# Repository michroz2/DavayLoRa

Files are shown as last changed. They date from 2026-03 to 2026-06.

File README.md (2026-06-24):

# DavayLoRa

Простая «дистанционная кнопка» для вызова на базе ЛоРа с радиусом действия порядка 300 метров.

ПЕРЕДАТЧИК имеет кнопку, а кроме этого: 
- статусный LED (обычно встроенный в кнопку);
- мониторинговый LED, который загорается _практически_ совместно с приёмником;
- дополнительный лед статуса батареи (встроенный лед платы микропроцессора).
- движковый выключатель. 

ПРИЁМНИК имеет:
- исполнительный ЛЕД - собственно вызывающая «лампочка» (состоит из 2 параллельных COB LED-ов);
- Баззер (моторчик с эксцентриком, осуществляющим вибрацию);
- Биппер (пищалка);
- DIP3 - переключатель выбора набора исполнительных элементов. В принципе можно выбрать все, часть или ни одного;
- дополнительный лед статуса, в том числе и батареи (встроенный лед платы микропроцессора).
- движковый выключатель. 

При включении как передатчика, так и приёмника:
- Показывается 1-секундное «приветствие» всеми исполнительными элементами, 
- затем встроенный лед статуса батареи (на передатчике - лед кнопки) выдаёт с интервалом 2 секунды 2 серии с числом вспышек в зависимости от напряжения батареи:
- - voltage > 3.5 - 2 по 1 разу
- - voltage > 3.6 - 2 по 2 раза
- - voltage > 3.7 - 2 по 3 раза
- - voltage > 3.8 - 2 по 4 раза
- - voltage > 4.0 - 2 по 5 раз

Ниже 3.5 вольт каждый прибор поморгает 7 раз и выключается. 
(То же самое, если заряжать от УСБ выключенный прибор.)
Проверка напряжения в дальнейшем происходит каждые 5 минут непрерывной работы.

- Передатчик переходит в режим ожидания _первого_ нажатия на кнопку.
(При этом передатчик не передаёт никаких комманд до первого нажатия.)
- Приёмник переходит в режим ожидания сигналов от передатчика. 
Приёмник никогда не передаёт никаких комманд первый, только отвечает на команды передатчика.
При отсутствии команд от передатчика приёмник с периодичностью 5 секунд выдаёт по 2 коротких вспышки статусным ледом.
- При первом нажатии на кнопку передатчик «просыпается» и начинает посылать команды включения/выключения и «пинги».
- При нажатии на кнопку передатчика передаётся сигнал на приёмник и в случае успешного приёма на приёмнике
срабатывают исполнительные элементы в соответствии с выбором переключателей DIP3. 
- Приёмник посылает ответную комманду, которая в случае успешного приёма передатчиком включает мониторинговый (и статусный) LED передатчика.
Таким образом, испольнительные элементы TX и RX включаются практически одновременно.
- При отпускании кнопки передатчика по команде гасятся исполнительные элементы приёмника и посылается ответная команда
передатчику, по получении которой выключаются мониторинговый и статусный LEDы передатчика.
Таким образом, при успешной связи испольнительные элементы TX и RX включаются и выключаются вместе.
- При отсутствии изменений состояния кнопки, передатчик начинает самостоятельно посылать «пинг» - сигнал с периодичностью 3 секунды.
Этот сигнал, в случае приёма, вызывает однократное мигание статусного ЛЕДа приёмника и ответ приёмника,
который, в свою очередь, в случае успешного приёма передатчиком вызывает однократное мигание статусного ЛЕДа передатчика.
Таким образом, в покое при успешной связи передатчик и приёмник практически синхронно однократно «моргают» с 
периодичностью 3 секунды.
- Включенные исполнительные элементы приёмника продолжительно работают максимально 2 секунды, после чего выключаются
(НЕ посылая сигнала об этом на передатчик). Поэтому при очень длительном нажатии на кнопку исполнительные 
элементы приёмника включаются каждые 3 секунды (по «пингу») и выключаются через 2 секунды после включения.
- При отсутствии ответа от приёмника передатчик с периодичностью 3 секунды выдаёт по 2 коротких вспышки статусным («кнопочным») ледом
(вместо нормально одной).
Таким образом: однократное «моргание» раз в 3 секунды - связь есть, а 2-х кратное моргание приёмника либо передатчика - связи нет.
- Если в течение часа не происходит нажатия кнопки, передатчик перестаёт посылать «пинг» и переходит в режим ожидания первого нажатия на кнопку.
(При этом приёмник, как и в случае потери сигнала, с периодичностью 5 секунд выдаёт по 2 коротких вспышки статусным ледом.)  

Взаимная настройка приёмника и передатчика (рабочей пары) производится в коде синхронным изменением частоты и/или рабочего адреса команд и последующей прошивкой. 

- 10.01.2022  - 	«причёсан» предыдущий код. Добавлены схемы соединения. Новый репозиторий github.
- 11.02.2022	-	исправлены баги и изменено моргание при отсутствии сигнала на 2 вспышки. 
- 11.02.2022	-	добавлено выключение пинга через 1 час отсутствия активности на кнопке
- 11.02.2022	-	добавлена библиотека GyverPower для засыпания процессора при разряженной батарее
- 17.01.2022	-	после проверки работы с севшими батарейками немного изменены напряжения отсечки
- 17.01.2022	-	Добавлено 1-секундное «приветствие» (а то севшие батарейки не мигали совсем)
- 18.01.2022	-	Исправлена бага со включением баззера и биппера на старте.
- 18.01.2022	-	В приветствие на старте добавлено включение всех исполнительных элементов.
- 18.01.2022	-	Добавлены инструкции для успешной работы с модулями с неисправным измерителем напряжения.
- 29.01.2022    -   Зафиксированы изменения Никиты:
- Диапазоны батареек
- Неработающий встроенный измеритель напряжения
- Рабочий адрес
Исправлен баг с непроверкой рабочего адреса на приёмнике
- TODO: Исправить схемы для самодельного измерителя напряжения - DONE 15.03.2023
- 01.02.2022 - Попытка ослабить влияние приборов разных пар, работающих на одной частоте.
- использованы Sync Word
- добавлена подстройка частоты на приёмнике
- добавлена задержка при получении несвоего пакета
- Сделан дебаунсинг на кнопке (на всякий случай)
- Файлы разбиты на «табы» для удобства работы в Ардуино ИДЕ
- 01.02.2022  - Убран ответный сигнал на «потухание»
- уменьшены задержки
- Все настройки вынесены в 1 место
- сделан ШИМ для Баззера/Биппера
- 02.02.2022 - Разнос по частотам
TODO: проверить дальность
- 21.02.2022 - Приёмник: включается статусный ЛЕД вместе с сигналом (на случай выключения всех ДИПов)
Вроде бы исправлена бага с «тусклым» статусным ледом для передатчика
- 22.02.2022 - Выяснена и ПОДправлена бага с показом отсутствия связи при первом нажатии при выключенном приёмнике. Исправить полностью нельзя, поскольку ещё неизвестно реальное время задержки сигнала. Но стало лучше. И в целом это не так критично.
- 27.02.2023 - Изготовление небольшой партии. Внесены изменения:
- - Изменена схема подключений выключателей. Теперь выключатель вставлен между + батарейного разъёма и контактом BAT. При этом
перерезается дорожка на плате, соединяющая эти места!
- - Платы BSFrance сортируются и "хорошие" используются в приёмниках, а "плохие" снабжаются резисторами и используются в передатчиках
- - В передатчике индикация статуса батарейки перенесена на лед кнопки
- - TODO: Исправить схемы! - DONE 15.03.2023
- - TODO: Добавить документацию по изготовлению. DONE 15.03.2023
- -  В приёмнике сделана возможность отказаться от измерителя батарейки вручную в программе (такие приёмники вместо заряда батарейки показывают 1 2сек. вспышку маленького белого ЛЕДа)
- 15.03.2023 - 
 - Добавлена программа измерения работы делителя TestBSF
 - Исправлены сигналы - Пинг, батарейные
 - Исправлена документация Whitepaper, Fritzen, Readme, Description - на приёмнике

Март 2026
- Произведена миграция разработки со среды Arduino IDE на систему редактора Cursor с PlatformIO. 
- Произведена миграция основного функционала на платформу ESP32 на модули HelTec Wireless Stick Lite V3

 - Automatic Battery detection (7a25770)

- Remastering of the project code for Cursor and PlatformIO and for ESP32 processor. Этап 1: Подготовка базового кода для Cursor (PlatformIO) - DONE Compile success (baafee2)

- Этап 2: Физическое тестирование и фиксация (Git)  **[DONE]** (258c84b)

- 12. Скомпилировать, прошить и протестировать работу проекта на новых модулях Heltec. - Библиотеки: Удалены LoRa.h и AVR-специфичная GyverPower.h. Добавлены RadioLib.h и esp_sleep.h. - Пины Heltec V3: Применена новая карта пинов. Vext (управление батареей) на 36, АЦП на 1. Исполнительные пины переведены на безопасные 41 и 42, статус LED на 35. Пины SPI и SX1262 прописаны для V3. - Радиомодуль (RadioLib): Синтаксис LoRa.* заменен на методы radio.*. Добавлено прерывание setFlag(), функция проверки checkReceive() и двухбайтовый SyncWord. Подстройка частоты (которая была в вашем RX) переведена в мегагерцы: radio.setFrequency(workFrequency / 1000000.0). - Батарея: Внедрен новый алгоритм поиска "пилы" (sawtooth ripple) напряжения для точного определения наличия аккумулятора, плюс множитель делителя 4.9. - Глубокий сон: Команды библиотеки GyverPower заменены на нативный esp_deep_sleep_start(). - Статус и батареечный led переведены на GPIO35 - встроенный LED платы (ad4e9e5)

- Test Heltec port with battery detection without peripherals (ae0388c)

- Кнопочный ЛЕД TX переведён на DigitalWright, Analog - не работал (7082ba0)

- Полный работающий код до комментов (a9ce04b)

- - код откомментирован. Конец Этапа 3. **[DONE]** (ddb04f5)

- Исправлено синк-слово в RX и TX radio.setSyncWord(RADIOLIB_SX126X_SYNC_WORD_PRIVATE); (c5465ac)

- Обе платы научились сохранять и читать переменные из внутренней флэш-памяти чипа. (a4ee276)

- Реализация отслеживания непрерывного удержания кнопки в течение 10 секунд. (Не оттестировано!) Новые картинки со схемами и Фритцинг файлы Новый Master-Slave план (73be0bc)

- Созданы Фритцен файлы для RX и TX (6016e98)

- Засыпание системы по 5-секундному удержанию кнопки USER (70e8a72)

- Что сделано: Макрос BATTERY_PERIOD удален и заменен на переменную batteryPeriod (по умолчанию 300000 мс). Добавлена переменная sleepLedDuration (по умолчанию 2000 мс). Обе переменные прописаны в функциях loadConfig() и saveConfig(). В TX время задержки при выключении заменено на delay(sleepLedDuration);. В RX в функции goToSleep() тройное мигание заменено на включение светодиода, ожидание sleepLedDuration и выключение (полная копия поведения TX). (65d18d0)

- Имплементация засыпания и пробуждения приборов. Всё кроме ЛоРы засыпает. Лора - следующим шагом. Исправлен Фритцин - кнопка TX теперь подключена к GPIO 7, чтообы срабатывало просыпание. (70659db)

- Исправление: Остановка радиомодуля SX1262 перед глубоким сном сброс флага receivedFlag = false; в функции отправки обоих приборов (чтобы не читалось эхо) (a02f814)       

- Убраны Аппаратные утечки тока (Шина SPI) в режиме сна Изменение: увеличен pingTimeoutRX («Моргание» сирены при потере пакета) Изменение: Добавлена переменная pingTimeoutRX в NVS для будущего портала (758ee98)

-  1.15 (Изменение: Защита от "горячего" процессора при заклинивании магнита или кнопки при пробуждении) (84e53e3)

- 1.16 (Исправление: Убрана системная ошибка Incorrect wakeup source) (a5febc6)

-  1.17 (Изменение: Добавлена стейт-машина и синхронная индикация CONFIG_STANDBY)  Новые команды протокола: CMD_CONFIG (216), CMD_CONFIG_OK (217), CMD_NORMAL_MODE (218) и CMD_NORMAL_MODE_OK (219). Стейт-машина в RX: Теперь у приемника есть переменная currentState, которая может быть STATE_NORMAL или STATE_CONFIG. Единый паттерн индикации: Добавлена функция processConfigLed(), которая использует неблокирующий таймер на 3600 мс (600 мс на три вспышки и ровно 3000 мс тишины). Она работает одинаково на TX и RX. Счетчик конфигурации: В TX добавлен configClickCount для отслеживания кликов внутри режима конфигурации. При 2-х кликах он посылает команду RX вернуться в норму и выходит сам. При 1 клике пока просто пишет в консоль заготовку для WiFi. Защита RX: Если связь между пультами потеряется во время конфигурации (сработает PING_TIMEOUT на RX), приемник автоматически вернется в нормальный рабочий режим, чтобы не зависнуть. (45c3731)

- 1.18 (Изменение: Добавлен выход из CONFIG_STANDBY при потере связи TX с RX) (5e32cd0)

- 1.19 (Изменение: Индикация CONFIG_STANDBY жестко привязана к keepalive-обмену) (1fd8ed0)

-  1.20 (Изменение: Добавлен запуск WiFi Captive Portal по 1 клику) По короткому клику в режиме STATE_CONFIG_STANDBY пульт (TX) поднимет точку доступа с именем DavayLoRa_TX. Включится DNS-сервер (Captive Portal), который будет перехватывать все запросы (например, когда телефон пытается проверить наличие интернета) и перенаправлять их на наш пульт. Мы сделаем простую страницу-заглушку («Captive Portal works!»), которая будет всплывать на экране телефона. Включится жесткий таймаут на 10 минут (600 000 мс). Если время истекло — WiFi выключается, и оба прибора возвращаются в STATE_NORMAL. При двойном клике (ручной выход) или потере связи с RX — WiFi также безопасно выключается, чтобы не высаживать батарею. (9bec538)

- 1.22 (Изменение: HTML-интерфейс вынесен в отдельный файл webpage.h) (825b148)

- 1.23 (Изменение: Добавлены все настройки (TX+RX) в NVS и Web UI) (fec22f1)

-  1.24 (Изменение: Вывод версии файла в лог,  Для вэб страницы: таймер и обработка кнопки Отмена) (8a20625)

- 1.25 (Изменение: Кнопки Сохранить и Отмена расположены вертикально) (a545de4)

-  1.30 (Изменение: Расширенное структурное логирование стейт-машины и действий)  Жёстко указаны Com9 для TX и Com10 для RX (008139f)

- 1.31 (Изменение: Динамическое имя WiFi AP на основе workAddress) (2442fd7)

- 1.32 Переменная sleepLedDuration соотв. «Индикация выключения (мс)» добавлена в общие параметры и передана на RX. (4f0b854)

- 1.33 (Исправлен выход из режима подготовки при одиночном клике) (3a69187)

- 1.34 Режим настройки исполнительных элементов
Протокол: В оба файла добавлены новые команды CMD_EXEC_CONFIG (223), CMD_EXEC_CONFIG_OK (224), CMD_CYCLE_EXEC (225) и CMD_CYCLE_EXEC_OK (226). Стейт-машина: В enum SystemState добавлено состояние STATE_EXEC_CONFIG. 
TX (Пульт): * Добавлена обработка тройного клика в processPreparationMode() для перехода в STATE_EXEC_CONFIG. Написана функция processExecConfigStandby(): 2 клика — выход в норму, 1 клик — отправка команды CMD_CYCLE_EXEC. При получении подтверждения CMD_CYCLE_EXEC_OK пульт парсит из байта данных новые состояния (LED и Buzzer), обновляет rxSettings и тут же вызывает saveConfig(). Добавлена функция processExecConfigLed() для индикации этого режима (две быстрые вспышки, в отличие от трех в обычном конфиге). 
RX (Приёмник): * Обработка перехода в STATE_EXEC_CONFIG с выключением нагрузки. Обработка CMD_CYCLE_EXEC: реализация переключения по кругу 00 -> 01 -> 10 -> 11 -> 00 с использованием битовых операций (state = (state + 1) % 4), сохранение в preferences, выдача подтверждения с новым состоянием и физическое воспроизведение 1-секундного сигнала с актуальными настройками. 
Защита processTimeOut() дополнена выходом из нового режима при потере связи. main.cpp (TX): В функцию processExecConfigStandby() добавлен блок else, который отправляет команду CMD_NORMAL_MODE и переводит TX в STATE_NORMAL, если пользователь совершил 3 и более кликов. (7cb630f)

- 1.36 (TX: Таймаут режима Exec-Config - Переключателей актуаторов) (5e81d3b)

- 1.38 (TX: Логирование таймаутов всех режимов) (c757fb9)

- 1.42 (TX: Финализация execTimeout - выход из режима настройки актуаторов, строгий аудит) (358ebb8)

- 1.43 (TX: Восстановление 2х-кратной индикации батареи при старте и полные логи setup) 
  1.43 (RX: Полное логирование setup и перенос Serial.begin) (4d7c811)

- 1.44 (TX: Фикс бага аппаратного ШИМ ESP32 при быстром loop) (добавлен флаг) (5334590)

- 1.45 (TX: Оптимизация таймера отправки в commSession) 
  1.45 (RX: Оптимизация шины APB через кэширование состояния LED чтобы не вызывать DigitalWrite в Лупе) (8c7dda2)     

- 1.46 (TX: Оптимизация логов, устранение пустых строк и фиксация всех state)   
  1.46 (RX: Оптимизация логов, устранение пустых строк) (fcc5bbd)

- 1.47 (TX, RX: Выделение подсистемы Battery в отдельные файлы) (30ef5de)

- 1.48 (TX, RX: Выделение подсистемы Config) (0082830)

- 1.49 (TX: Выделение WebPortal, исправление бага с баззером и текста Success) (74c160f)

- 1.50 (TX, RX: Выделение RadioComm) (a1171e7)

-  1.51 (TX: Фикс утечек тока в Deep Sleep - перевод SPI пинов в INPUT) (2ca7900)

-  1.52 (TX, RX: Перегруппировка функций в main.cpp для удобочитаемости) (505aa3e)

-  1.52 (TX, RX : Перегруппировка функций для удобочитаемости, добаавление версий во все файлы) (9404072)

- PRODUCTION! Выключен Логгинг. Полная рабочая версия для заливки, изготовления корпуса и в производство. (95cd924)

-  1.54 (TX, RX: Идеальный сон - аппаратное удержание состояний пинов VEXT и ADC) (2beb1b9)

- 1.55 (RX, TX: Оптимизация Active Mode - отключение Wi-Fi на старте и FreeRTOS Yield = добавлен Delay(1)) (da93657)

-  1.59 (Добавлено логирование всех состояний кнопки USER),  Исправлен баг с записью длины таймера выключения  Пока всё. (0f3db1e)

- 1.59 ( Добавлено логирование всех состояний кнопки USER) (6eeb2c8)

- 1.64 (TX: Плавный безопасный спуск мощности (Target clamping) и связка Action-Ping) (cc02bf4)
- 1.64 (RX: Плавный безопасный спуск мощности (Target clamping) и связка Action-Ping) (cc02bf4)

-  1.66 (TX: Интеграция Web-настроек мощности + Возврат комментариев форматирования)  1.67 (RX: Использование глобального лимита maxPower + Полное восстановление структуры и комментариев)  
   1.64 (Coonfig RX: Добавлен прием ограничения максимальной мощности)  Короче: параметры мощности и динамической подстройки выведены на вэб (5e2f11d)        

- Add Google Drive temp files to gitignore (d248343)

- 1.68 Изменение: Улучшен вывод логов пинга (разделение локального и удаленного RSSI). (e57c498)

- 1.71 - Добавлен справочный вывод рабочей частоты %FREQ_MHZ% на веб-странице настроек (8075266)

- 1.72 Внедрена вычисляемая рабочая частота и число каналов 81 (4c55ca0)

- Создание веб-инсталлятора для прошивки DavayLoRa_HT_RX и DavayLoRa_HT_TX 
Описание: 
1. Создание веб-инсталлятора для прошивки DavayLoRa_HT_RX и DavayLoRa_HT_TX 
2. Создание файла build_factory.py для объединения бинарных файлов для веб-инсталлятора 
3. Создание файла platformio.ini для конфигурации проекта 
4. Создание файла src/main.cpp для основного кода проекта 
5. Создание файла web_installer/index.html для веб-инсталлятора 
6. Создание файла web_installer/manifest.json для конфигурации проекта 
7. Создание файла web_installer/factory.bin для прошивки проекта 
Симметрично для DavayLoRa_HT_TX и DavayLoRa_HT_RX (32dc188)

- Добавлен файл index.html для выбора прошивки DavayLoRa (64c7d2c)

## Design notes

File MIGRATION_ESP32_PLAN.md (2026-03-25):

# План миграции проекта DavayLoRa

## Этап 1: Подготовка базового кода для Cursor (PlatformIO)
1. Собрать код передатчика (TX) под старую плату (BSFrance) в PlatformIO. **[DONE]**
2. Организовать структуру проекта: разделить код TX и RX по отдельным корневым папкам (например, `DavayLoRa_TX` и `DavayLoRa_RX`), чтобы избежать конфликта компиляторов. **[DONE]**
3. Добавить в рабочую область код приемника (RX). **[DONE]**
4. Адаптировать код RX под стандарт C++ для PlatformIO (объединение `.ino` файлов, переименование в `.cpp`, добавление `<Arduino.h>` и прототипов функций, исправление форматов данных). **[DONE]**
5. Скомпилировать проект RX без ошибок для платы BSFrance. **[DONE]**

## Этап 2: Физическое тестирование и фиксация (Git) **[DONE]**
6. Прошить физические модули (BSFrance / Adafruit) новым скомпилированным кодом TX и RX.
7. Проверить реальную работоспособность связи по LoRa и всех функций (отклик кнопки, светодиоды, логика сна и измерения батареи).
8. Зафиксировать изменения в Git и отправить на GitHub в новую ветку (branch) `Cursor`.

## Этап 3: Переход на новую аппаратную платформу (Heltec ESP32)
9. Создать в Git новую ветку (например, `heltec-port`) на базе ветки `Cursor`.
10. Изменить конфигурацию `platformio.ini` для платы `heltec_wireless_stick_lite`.
11. Адаптировать библиотеки и пины (включая замену AVR-специфичной библиотеки `GyverPower` на встроенные механизмы глубокого сна ESP32) с обязательным пошаговым контролем.
12. Скомпилировать, прошить и протестировать работу проекта на новых модулях Heltec.
### Что было изменено:
- Библиотеки: Удалены LoRa.h и AVR-специфичная GyverPower.h. Добавлены RadioLib.h и esp_sleep.h.
- Пины Heltec V3: Применена новая карта пинов. Vext (управление батареей) на 36, АЦП на 1. Исполнительные пины переведены на безопасные 41 и 42, статус LED на 35. Пины SPI и SX1262 прописаны для V3.
- Радиомодуль (RadioLib): Синтаксис LoRa.* заменен на методы radio.*. Добавлено прерывание setFlag(), функция проверки checkReceive() и двухбайтовый SyncWord. Подстройка частоты (которая была в вашем RX) переведена в мегагерцы: radio.setFrequency(workFrequency / 1000000.0).
- Батарея: Внедрен новый алгоритм поиска "пилы" (sawtooth ripple) напряжения для точного определения наличия аккумулятора, плюс множитель делителя 4.9.
- Глубокий сон: Команды библиотеки GyverPower заменены на нативный esp_deep_sleep_start().
- Статус и батареечный led переведены на GPIO35 - встроенный LED платы
(Кнопочный ЛЕД TX переведён на DigitalWright, Analog - не работал)
- DigitalWrite и AnalogWrite оказалось нельзя смешивать на ESP32
- код откомментирован. Конец Этапа 3. 
**[DONE]**

Дальнейший план: имплементировать бесконтактное включение-выключение и настройку модулей без необходимости перепрошивки.
См Master-Slave_PLAN

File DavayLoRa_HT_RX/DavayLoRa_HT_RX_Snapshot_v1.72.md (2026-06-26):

# Project: DavayLoRa_HT_RX Snapshot V1.72

## File: .\src\Battery.cpp
```cpp
/**
 * @file Battery.cpp
 * @version 1.53
 * @brief Реализация подсистемы питания (RX)
 */
 #include "Battery.h"

 // Локальные макросы отладки
 #define DEBUG_ENABLE // Логирование выключено
 #ifdef DEBUG_ENABLE
 #define DEBUG(x) Serial.print(x)
 #define DEBUGln(x) Serial.println(x)
 #else
 #define DEBUG(x)
 #define DEBUGln(x)
 #endif
 
 bool isBatteryConnected = false;
 
 // Проверка наличия подключенной батареи при запуске
 bool testBattery() { 
    if (batteryVoltageOK(5)) return true;
    return false;
 } // конец функции testBattery
 
 // Серия замеров напряжения для фильтрации шумов и проверки стабильности
 bool batteryVoltageOK(byte tries) {
    float minV = 5.0, maxV = 0.0;
    for (byte i = 0; i < tries; i++) {
      float currentVBat = batteryVoltage();
      if (currentVBat < minV) minV = currentVBat; 
      if (currentVBat > maxV) maxV = currentVBat; 
      if ((currentVBat > 4.5) || (currentVBat < 2.5)) return false;
      delay(150);
    } // конец цикла замеров
    if ((maxV - minV) > 0.05) return false;
    return true;
 } // конец функции batteryVoltageOK
 
 // Считывание напряжения через АЦП микроконтроллера
 float batteryVoltage() {
    digitalWrite(PIN_ADC_CTRL, LOW); delay(10); // Включение цепи делителя напряжения                      
    float measuredvbat = analogRead(PIN_BATTERY_INTERNAL);
    digitalWrite(PIN_ADC_CTRL, HIGH); // Отключение делителя для экономии энергии
    measuredvbat *= 3.3; measuredvbat /= 4095.0; measuredvbat *= HELTEC_BATTERY_MULTIPLIER; 
    return measuredvbat;
 } // конец функции batteryVoltage
 
 // Периодическая проверка. Если разряд критический — выключение устройства
 void processBattery() { 
    if (batteryVoltage() < BATTERY_MIN_VOLTAGE) stopWorking(); 
 } // конец функции processBattery
 
 // Индикация заряда статусной лампой (до 5 вспышек)
 void showBatteryVoltage() {
    float voltage = batteryVoltage();
    if (voltage > BATTERY_VOLTAGE_1) flashBatteryLEDOnce(); 
    if (voltage > BATTERY_VOLTAGE_2) flashBatteryLEDOnce(); 
    if (voltage > BATTERY_VOLTAGE_3) flashBatteryLEDOnce(); 
    if (voltage > BATTERY_VOLTAGE_4) flashBatteryLEDOnce(); 
    if (voltage > BATTERY_VOLTAGE_5) flashBatteryLEDOnce(); 
 } // конец функции showBatteryVoltage
 
 // Индикация отсутствия батареи (например, питание от USB)
 void showNoBattery() { 
    digitalWrite(PIN_BATTERY_LED, 1); delay(2000); digitalWrite(PIN_BATTERY_LED, 0); delay(250); 
 } // конец функции showNoBattery
 
 void flashBatteryLEDOnce() { 
    digitalWrite(PIN_BATTERY_LED, 1); delay(250); digitalWrite(PIN_BATTERY_LED, 0); delay(250); 
 } // конец функции flashBatteryLEDOnce
 
 void flashLedBattery(byte times) { 
    for (int i = 0; i < times; i++) flashBatteryLEDOnce(); 
    delay(200); 
 } // конец функции flashLedBattery
 
 // Принудительное засыпание приемника для защиты аккумулятора
 void stopWorking() { 
    DEBUGln(F("[STATE] BATTERY DEAD! Stopping..."));
    flashLedBattery(7); digitalWrite(PIN_BATTERY_LED, 0); delay(3000); 
    flashLedBattery(7); digitalWrite(PIN_BATTERY_LED, 0); enterDeepSleep(); 
 } // конец функции stopWorking
```

---

## File: .\src\Battery.h
```cpp
/**
 * @file Battery.h
 * @version 1.53
 * @brief Подсистема питания и контроля батареи (RX)
 * Описание: Отвечает за замеры напряжения аккумулятора и защиту от глубокого разряда.
 */
 #ifndef BATTERY_H
 #define BATTERY_H
 
 #include <Arduino.h>
 
 // --- Пороги батареи ---
 #define BATTERY_MIN_VOLTAGE 3.5
 #define BATTERY_VOLTAGE_1 3.6
 #define BATTERY_VOLTAGE_2 3.7
 #define BATTERY_VOLTAGE_3 3.8
 #define BATTERY_VOLTAGE_4 3.9
 #define BATTERY_VOLTAGE_5 4.0
 
 // --- Пины и константы батареи ---
 #define PIN_BATTERY_LED 35     
 #define PIN_BATTERY_INTERNAL 1     
 #define PIN_ADC_CTRL 37            
 #define HELTEC_BATTERY_MULTIPLIER 4.9 
 
 extern bool isBatteryConnected;
 
 // Внешние зависимости (из main.cpp)
 extern void enterDeepSleep();
 
 // Прототипы функций
 bool testBattery();
 bool batteryVoltageOK(byte tries);
 float batteryVoltage();
 void processBattery();
 void showBatteryVoltage();
 void showNoBattery();
 void flashBatteryLEDOnce();
 void flashLedBattery(byte times);
 void stopWorking();
 
 #endif
```

---

## File: .\src\Config.cpp
```cpp
/**
 * @file Config.cpp
 * @version 1.64 (RX: Добавлен прием ограничения максимальной мощности)
 * @brief Реализация загрузки и сохранения настроек (RX)
 */
 #include "Config.h"

 // Локальные макросы отладки
 #define DEBUG_ENABLE // Логирование ВКЛЮЧЕНО
 #ifdef DEBUG_ENABLE
 #define DEBUG(x) Serial.print(x)
 #define DEBUGln(x) Serial.println(x)
 #else
 #define DEBUG(x)
 #define DEBUGln(x)
 #endif
 
 Preferences preferences;
 
 byte workAddress = 0;                 
 int pwmledBrightness = 35;            
 int buzzerVolume = 255;               
 unsigned long cutoffTime = 2000;      
 unsigned long pingTimeout = 9000;     
 unsigned long stuckSleepTime = 10000; 
 bool measurebattery = true;           
 unsigned long batteryPeriod = 300000;    
 unsigned long sleepLedDuration = 2000;   
 unsigned long configTimeout = 600000;
 int maxPower = 20; // Инициализация лимита мощности
 
 unsigned long wakeUpHoldTime = 2000;     
 unsigned long wakeUpReleaseWindow = 2000; 
 
 // По умолчанию включен только свет
 bool enableBigLed = true;             
 bool enableBuzzer = false;            
 
 // Загрузка сохраненных настроек при включении приемника
 void loadConfig() {
    DEBUGln(F("--- Loading config from NVS ---"));
    preferences.begin("davaylora", false);
    
    workAddress = preferences.getUChar("workAddress", 0);
    measurebattery = preferences.getBool("measureBat", true);
    pwmledBrightness = preferences.getInt("bigLedBright", 35);
    buzzerVolume = preferences.getInt("buzzerVol", 255);
    cutoffTime = preferences.getULong("cutoffTime", 2000);
    pingTimeout = preferences.getULong("pingTimeout", 9000);
    stuckSleepTime = preferences.getULong("stuckSleep", 10000);
    configTimeout = preferences.getULong("confTo", 600000);
    maxPower = preferences.getInt("maxPwr", 20);
    
    // ИСПРАВЛЕНИЕ: Используем короткий ключ "sleepLedDur" (менее 15 символов)
    sleepLedDuration = preferences.getULong("sleepLedDur", 2000);
    
    enableBigLed = preferences.getBool("enBigLed", true);
    enableBuzzer = preferences.getBool("enBuzzer", false);
    
    batteryPeriod = preferences.getULong("batPeriod", 300000);
    wakeUpHoldTime = preferences.getULong("wkUpHold", 2000);
    wakeUpReleaseWindow = preferences.getULong("wkUpRel", 2000);
    
    preferences.end();
    DEBUGln(F("Config loaded."));
 } // конец функции loadConfig
 
 // Сохранение новых настроек, когда пульт присылает их пакет по воздуху
 void saveConfigFromPacket(ConfigPacket* p) {
    DEBUGln(F("--- Saving received config struct to NVS ---"));
    DEBUG(F("workAddress: ")); DEBUGln(p->workAddress);
    DEBUG(F("rxPwmledBrightness: ")); DEBUGln(p->rxPwmledBrightness);
    DEBUG(F("rxBuzzerVolume: ")); DEBUGln(p->rxBuzzerVolume);
    DEBUG(F("maxPower: ")); DEBUGln(p->maxPower);
    
    preferences.begin("davaylora", false);
    
    preferences.putUChar("workAddress", p->workAddress);
    preferences.putBool("measureBat", p->measurebattery);
    preferences.putULong("batPeriod", p->batteryPeriod);
    preferences.putULong("wkUpHold", p->wakeUpHoldTime);
    preferences.putULong("wkUpRel", p->wakeUpReleaseWindow);
    preferences.putULong("stuckSleep", p->stuckSleepTime);
    preferences.putULong("confTo", p->configTimeout);
    
    // ИСПРАВЛЕНИЕ: Используем короткий ключ "sleepLedDur"
    preferences.putULong("sleepLedDur", p->sleepLedDuration);
    
    preferences.putBool("enBigLed", p->rxEnableBigLed);
    preferences.putInt("bigLedBright", p->rxPwmledBrightness);
    preferences.putBool("enBuzzer", p->rxEnableBuzzer);
    preferences.putInt("buzzerVol", p->rxBuzzerVolume);
    preferences.putULong("cutoffTime", p->rxCutoffTime);
    preferences.putULong("pingTimeout", p->pingTimeoutRX);
    preferences.putInt("maxPwr", p->maxPower);
    
    // Обновляем глобальную переменную в памяти (важно для работы прямо сейчас)
    maxPower = p->maxPower;
    
    preferences.end();
    DEBUGln(F("Config saved."));
 } // конец функции saveConfigFromPacket
```

---

## File: .\src\Config.h
```cpp
/**
 * @file Config.h
 * @version 1.64
 * @brief Глобальные настройки и работа с энергонезависимой памятью NVS (RX)
 * Описание: Хранит параметры приемника и принимает новые конфигурации от пульта.
 */
 #ifndef CONFIG_H
 #define CONFIG_H
 
 #include <Arduino.h>
 #include <Preferences.h>
 
 // Структура пакета настроек, приходящая от TX при синхронизации (CMD_SYNC_CONFIG)
 #pragma pack(push, 1)
 struct ConfigPacket {
    byte workAddress;
    bool measurebattery;
    unsigned long batteryPeriod;
    unsigned long wakeUpHoldTime;
    unsigned long wakeUpReleaseWindow;
    unsigned long stuckSleepTime;
    unsigned long configTimeout;
    unsigned long sleepLedDuration;
    
    bool rxEnableBigLed;
    int rxPwmledBrightness;
    bool rxEnableBuzzer;
    int rxBuzzerVolume;
    unsigned long rxCutoffTime;
    unsigned long pingTimeoutRX;
    int maxPower; // Принимаем ограничение мощности от TX
 };
 #pragma pack(pop)
 
 // Глобальный объект Preferences (нужен в main.cpp для CMD_CYCLE_EXEC)
 extern Preferences preferences;
 
 // Локальные переменные RX (активные настройки)
 extern byte workAddress;                 
 extern int pwmledBrightness;            
 extern int buzzerVolume;               
 extern unsigned long cutoffTime;      
 extern unsigned long pingTimeout;     
 extern unsigned long stuckSleepTime; 
 extern bool measurebattery;           
 extern unsigned long batteryPeriod;    
 extern unsigned long sleepLedDuration;   
 extern unsigned long configTimeout;
 extern int maxPower; // Лимит мощности передачи
 
 extern unsigned long wakeUpHoldTime;     
 extern unsigned long wakeUpReleaseWindow; 
 
 // Флаги активных исполнительных устройств (Свет / Вибрация)
 extern bool enableBigLed;             
 extern bool enableBuzzer;            
 
 // Прототипы
 void loadConfig();
 void saveConfigFromPacket(ConfigPacket* p);
 
 #endif
```

---

## File: .\src\main.cpp
```cpp
/** Gemini
 * @file main.cpp (RX) 
 * @version 1.72 Внедрена вычисляемая рабочая частота и число каналов 81
 * @brief ПОЛНЫЙ ИСХОДНЫЙ КОД ПРИЁМНИКА (DavayLoRa)
 * Описание: Ядро стейт-машины, логика переключения режимов и обработка геркона/кнопки.
 */

 #include <Arduino.h>
 #include <esp_sleep.h>
 #include <driver/rtc_io.h>
 #include <driver/gpio.h> // Добавлено для функций заморозки пинов (gpio_hold)
 #include <WiFi.h>        // Добавлено для принудительного отключения модема на старте
 
 #include "Battery.h" 
 #include "Config.h"   
 #include "RadioComm.h" 
 
 // ======================= АППАРАТНАЯ КОНФИГУРАЦИЯ =======================
 
 // Распиновка Heltec V3
 #define PIN_SIGNAL_LED      41     // Сигнальный свет для актера
 #define PIN_SIGNAL_BUZZERS  42     // Вибрация / Зуммер
 #define PIN_REED            7      // Магнитный переключатель (геркон) для включения
 #define PIN_USER            0      // Кнопка PRG на плате
 #define PIN_STATUS_LED      35     // Мелкий светодиод обратной связи
 #define PIN_VEXT 36                
 
 // ======================= ГЛОБАЛЬНЫЕ ПЕРЕМЕННЫЕ И МАКРОСЫ =======================
 
 // Локальные макросы отладки
 #define DEBUG_ENABLE // Логирование ВКЛЮЧЕНО
 #ifdef DEBUG_ENABLE
 #define DEBUG(x) Serial.print(x)
 #define DEBUGln(x) Serial.println(x)
 #else
 #define DEBUG(x)
 #define DEBUGln(x)
 #endif
 
 #define EVERY_MS(x) \
    static uint32_t tmr;\
    bool flg = millis() - tmr >= (x);\
    if (flg) { tmr = millis(); }\
    if (flg)
 
 bool signalStatus; // Активно ли удержание кнопки на пульте в данный момент
 
 unsigned long pingTimeOutLastTime; // Таймер Failsafe для отключения при обрыве связи
 unsigned long cutoffTimer = 0;     // Таймер защиты от слишком долгого удержания сигнала
 
 // Состояния RX: Рабочий режим, Настройка (ожидание Wi-Fi), Настройка сигнала (Свет/Вибро)
 enum SystemState { STATE_NORMAL, STATE_CONFIG, STATE_EXEC_CONFIG };
 SystemState currentState = STATE_NORMAL;
 
 bool configBlinkActive = false;
 unsigned long configBlinkStartTime = 0;
 
 bool execBlinkActive = false;
 unsigned long execBlinkStartTime = 0;
 
 // --- ПРОТОТИПЫ ---
 void updateStatusLed(bool ledStatus);
 void flashStatusLEDOnce();
 void flashStatusLed(byte times);
 void processConfigLed();
 void processExecConfigLed();
 void enterDeepSleep();
 void runWakeUpProtection(uint8_t wakeupPin);
 void goToSleep();
 void processUserButton();
 void processCommand();
 void processSignal();
 void processCutoff();
 void processTimeOut();
 
 // ======================= ИНДИКАЦИЯ (LED & BUZZER) =======================
 
 void updateStatusLed(bool ledStatus) { 
    static int lastLedState = -1;
    int newState = ledStatus ? HIGH : LOW;
    if (lastLedState != newState) {
      digitalWrite(PIN_STATUS_LED, newState);
      lastLedState = newState;
    } // конец защиты от аппаратного спама
 } // конец функции updateStatusLed
 
 void flashStatusLEDOnce() { 
    digitalWrite(PIN_STATUS_LED, 1); delay(250); digitalWrite(PIN_STATUS_LED, 0); delay(250); 
 } // конец функции flashStatusLEDOnce
 
 void flashStatusLed(byte times) { 
    for (int i = 0; i < times; i++) flashStatusLEDOnce(); 
    delay(200); 
 } // конец функции flashStatusLed
 
 void processConfigLed() {
    if (!configBlinkActive) return;
    unsigned long elapsed = millis() - configBlinkStartTime;
    if (elapsed < 100) updateStatusLed(true); 
    else if (elapsed < 200) updateStatusLed(false); 
    else if (elapsed < 300) updateStatusLed(true); 
    else if (elapsed < 400) updateStatusLed(false); 
    else if (elapsed < 500) updateStatusLed(true); 
    else { updateStatusLed(false); configBlinkActive = false; }
 } // конец функции processConfigLed
 
 void processExecConfigLed() {
    if (!execBlinkActive) return;
    unsigned long elapsed = millis() - execBlinkStartTime;
    if (elapsed < 100) updateStatusLed(true); 
    else if (elapsed < 200) updateStatusLed(false); 
    else if (elapsed < 300) updateStatusLed(true); 
    else { updateStatusLed(false); execBlinkActive = false; }
 } // конец функции processExecConfigLed
 
 // ======================= УПРАВЛЕНИЕ ПИТАНИЕМ И СНОМ =======================
 
 // Оптимизация Deep Sleep: Перевод всей периферии в режим минимального энергопотребления
 void enterDeepSleep() {
    DEBUGln(F("[STATE] ---> ENTERING DEEP SLEEP"));
    radio.sleep();
    SPI.end(); // Выключение аппаратной шины SPI
    
    // Блокировка паразитных токов на пинах LoRa путем перевода их в режим высокого сопротивления (INPUT)
    pinMode(csPin, INPUT); pinMode(mosiPin, INPUT); pinMode(misoPin, INPUT);
    pinMode(sckPin, INPUT); pinMode(resetPin, INPUT); pinMode(busyPin, INPUT);
    pinMode(irqPin, INPUT);
    
    // Обесточивание периферии и делителя батареи
    pinMode(PIN_VEXT, OUTPUT); digitalWrite(PIN_VEXT, HIGH);
    pinMode(PIN_ADC_CTRL, OUTPUT); digitalWrite(PIN_ADC_CTRL, HIGH);
    
    // --- ИДЕАЛЬНЫЙ СОН: Заморозка пинов для исключения плавающих уровней ---
    gpio_hold_en((gpio_num_t)PIN_VEXT);
    gpio_hold_en((gpio_num_t)PIN_ADC_CTRL);
    gpio_deep_sleep_hold_en();
    // -----------------------------------------------------------------------
 
    pinMode(PIN_STATUS_LED, OUTPUT); digitalWrite(PIN_STATUS_LED, LOW);
    pinMode(PIN_SIGNAL_LED, OUTPUT); digitalWrite(PIN_SIGNAL_LED, LOW);
    pinMode(PIN_SIGNAL_BUZZERS, OUTPUT); digitalWrite(PIN_SIGNAL_BUZZERS, LOW);
    
    rtc_gpio_pullup_en((gpio_num_t)PIN_REED);
    rtc_gpio_pulldown_dis((gpio_num_t)PIN_REED);
    
    // Защита от "залипания" магнита: если он не был убран, уходим в сон по таймеру, а не по прерыванию
    if (digitalRead(PIN_REED) == LOW) {
      DEBUGln(F("[STATE] Reed is STUCK. Sleeping with timer..."));
      esp_sleep_enable_timer_wakeup(stuckSleepTime * 1000ULL);
    } else {
      DEBUGln(F("[STATE] Normal sleep. Wakeup on EXT0 (Reed). Good night!"));
      esp_sleep_enable_ext0_wakeup((gpio_num_t)PIN_REED, 0);
    } // конец проверки залипания геркона
    esp_deep_sleep_start();
 } // конец функции enterDeepSleep
 
 // Защита от дребезга и случайного касания магнита при пробуждении
 void runWakeUpProtection(uint8_t wakeupPin) {
    esp_sleep_wakeup_cause_t wakeup_reason = esp_sleep_get_wakeup_cause();
    if (wakeup_reason == ESP_SLEEP_WAKEUP_TIMER) enterDeepSleep(); 
    
    if (wakeup_reason == ESP_SLEEP_WAKEUP_EXT0) {
      DEBUGln(F("[STATE] Woke up from Deep Sleep. Checking protection..."));
      updateStatusLed(true);
      unsigned long startHold = millis();
      // Требование удержания магнита не менее wakeUpHoldTime (2 сек)
      while (millis() - startHold < wakeUpHoldTime) {
        if (digitalRead(wakeupPin) == HIGH) { 
          DEBUGln(F("[ACTION] Magnet released too early. Going back to sleep."));
          updateStatusLed(false); enterDeepSleep(); 
        } // конец проверки раннего отпускания
        delay(10);
      } // конец цикла удержания
      
      DEBUGln(F("[STATE] Waiting for magnet release in window..."));
      unsigned long startReleaseWindow = millis();
      bool releasedInWindow = false;
      // Требование убрать магнит в течение окна wakeUpReleaseWindow
      while (millis() - startReleaseWindow < wakeUpReleaseWindow) {
        updateStatusLed((millis() % 200) < 100); 
        if (digitalRead(wakeupPin) == HIGH) { 
          DEBUGln(F("[ACTION] Magnet released! WAKE UP SUCCESS."));
          releasedInWindow = true; break; 
        } // конец проверки отпускания в окне
        delay(10);
      } // конец цикла окна отпускания
      
      if (!releasedInWindow) { 
        DEBUGln(F("[ACTION] Magnet held too long. Going back to sleep."));
        updateStatusLed(false); enterDeepSleep(); 
      } // конец условия ошибки окна отпускания
      updateStatusLed(false); 
    } // конец проверки причины просыпания EXT0
 } // конец функции runWakeUpProtection
 
 void goToSleep() {
    updateStatusLed(true); delay(sleepLedDuration); updateStatusLed(false);
    enterDeepSleep();
 } // конец функции goToSleep
 
 // ======================= ОБРАБОТКА ВВОДА (КНОПКИ) =======================
 
 void processUserButton() {
    static unsigned long userButtonTimer = 0;
    static bool prevUserState = HIGH;
    bool currUserState = digitalRead(PIN_USER);
    
    // Отслеживание физического нажатия и отпускания кнопки
    if (currUserState != prevUserState) {
      if (currUserState == LOW) {
        DEBUGln(F("[ACTION] USER Button PRESSED"));
        userButtonTimer = millis();
      } else {
        DEBUGln(F("[ACTION] USER Button RELEASED"));
        userButtonTimer = 0;
      }
      prevUserState = currUserState;
    } // конец отслеживания состояний
    
    // Таймер долгого удержания (5 секунд)
    if (currUserState == LOW && userButtonTimer > 0) {
      if (millis() - userButtonTimer > 5000) {
        DEBUGln(F("[ACTION] USER button held 5s -> Local Sleep"));
        goToSleep(); 
        userButtonTimer = 0; // Сброс таймера для предотвращения спама
      } // конец проверки удержания USER
    } // конец проверки зажатия
 } // конец функции processUserButton
 
 // ======================= РАДИООБМЕН =======================
 
 // Исполнение команд, принятых из эфира
 void processCommand() {
    int currentRssi = (int)radio.getRSSI();
    DEBUG(F("[RADIO] RX Cmd: ")); DEBUG(rcvCmd); DEBUG(F(" | RSSI: ")); DEBUGln(currentRssi);
 
    switch (rcvCmd) {
      case CMD_SIGNAL:
        // Главный рабочий сигнал (Вкл/Выкл свет или вибро у актера)
        signalStatus = rcvData; processSignal();
        radio.setOutputPower(maxPower); // Ответы на Action всегда на максимум из конфига
        if (signalStatus) sendMessage(rcvAddress, CMD_SIGNAL_OK, signalStatus); 
        break;
      case CMD_PING: {
        // Синхронное моргание для подтверждения качества связи и АДАПТИВНАЯ МОЩНОСТЬ
        // Распаковка требуемой мощности от TX
        int reqPower = (int)(rcvData & 0x7F) - 10;
        signalStatus = (rcvData >> 7) & 0x01;
        
        processSignal();
        updateStatusLed(true);
        
        // Безопасная упаковка RSSI (защита от отрицательного переполнения)
        int safeRssi = abs(currentRssi);
        if (safeRssi < 30) safeRssi = 30; // Лимит SX1262
        byte packedRssi = (byte)(safeRssi - 30);
        byte replyByte = (signalStatus << 7) | (packedRssi & 0x7F);
        
        radio.setOutputPower(reqPower);
        DEBUG(F("[PING] Reply Power: ")); DEBUG(reqPower); DEBUGln(F(" dBm"));
        sendMessage(rcvAddress, CMD_PING_OK, replyByte);     
        
        delay(50); updateStatusLed(false);
        radio.setOutputPower(maxPower); // Возврат на maxPower для готовности к Action
        break;
      } // конец обработки CMD_PING
      case CMD_SLEEP:
        radio.setOutputPower(maxPower);
        sendMessage(rcvAddress, CMD_SLEEP_OK, 1); 
        delay(100); goToSleep();
        break;
      case CMD_CONFIG:
        DEBUGln(F("[STATE] ---> STATE_CONFIG"));
        currentState = STATE_CONFIG;
        pingTimeOutLastTime = millis();
        radio.setOutputPower(maxPower);
        sendMessage(rcvAddress, CMD_CONFIG_OK, 1);
        configBlinkActive = true; configBlinkStartTime = millis(); 
        analogWrite(PIN_SIGNAL_LED, 0); analogWrite(PIN_SIGNAL_BUZZERS, 0);
        break;
      case CMD_EXEC_CONFIG:
        DEBUGln(F("[STATE] ---> STATE_EXEC_CONFIG"));
        currentState = STATE_EXEC_CONFIG;
        pingTimeOutLastTime = millis();
        radio.setOutputPower(maxPower);
        sendMessage(rcvAddress, CMD_EXEC_CONFIG_OK, 1);
        execBlinkActive = true; execBlinkStartTime = millis(); 
        analogWrite(PIN_SIGNAL_LED, 0); analogWrite(PIN_SIGNAL_BUZZERS, 0);
        break;
      case CMD_CYCLE_EXEC: {
        // Смена исполнительных устройств (свет -> вибро -> свет+вибро -> ничего) на лету
        DEBUGln(F("[ACTION] CMD_CYCLE_EXEC received. Cycling actuators."));
        byte state = (enableBuzzer ? 2 : 0) | (enableBigLed ? 1 : 0);
        state = (state + 1) % 4;
        
        enableBigLed = (state & 0x01);
        enableBuzzer = (state & 0x02) >> 1;
        
        preferences.begin("davaylora", false);
        preferences.putBool("enBigLed", enableBigLed);
        preferences.putBool("enBuzzer", enableBuzzer);
        preferences.end();
        
        DEBUG(F("[STATE] Actuators updated. LED: ")); DEBUG(enableBigLed);
        DEBUG(F(", BUZZER: ")); DEBUGln(enableBuzzer);
        
        radio.setOutputPower(maxPower);
        sendMessage(rcvAddress, CMD_CYCLE_EXEC_OK, state);
        
        // Демонстрация актеру выбранного режима (длится 1 сек)
        signalStatus = true; processSignal(); 
        delay(1000); 
        signalStatus = false; processSignal();
        break;
      } // конец обработки CMD_CYCLE_EXEC
      case CMD_NORMAL_MODE:
        DEBUGln(F("[STATE] ---> STATE_NORMAL"));
        currentState = STATE_NORMAL;
        pingTimeOutLastTime = millis();
        updateStatusLed(false);
        radio.setOutputPower(maxPower);
        sendMessage(rcvAddress, CMD_NORMAL_MODE_OK, 1);
        break;
    } // конец switch
    rcvCmd = 0; 
 } // конец функции processCommand
 
 // Физическое включение света и вибрации (с учетом настроек яркости и громкости)
 void processSignal() {
    cutoffTimer = millis(); 
    if (signalStatus && enableBigLed) analogWrite(PIN_SIGNAL_LED, pwmledBrightness);
    else analogWrite(PIN_SIGNAL_LED, 0);
    
    if (signalStatus && enableBuzzer) analogWrite(PIN_SIGNAL_BUZZERS, buzzerVolume);
    else analogWrite(PIN_SIGNAL_BUZZERS, 0);
    
    digitalWrite(PIN_STATUS_LED, signalStatus);
 } // конец функции processSignal
 
 // Защитная отсечка: если сигнал подается слишком долго, он отключается для экономии батареи
 void processCutoff() {
    if (signalStatus && (millis() - cutoffTimer > cutoffTime)) {
      DEBUGln(F("[ACTION] Signal Cutoff Triggered!"));
      signalStatus = 0;
      analogWrite(PIN_SIGNAL_LED, 0); analogWrite(PIN_SIGNAL_BUZZERS, 0);
      digitalWrite(PIN_STATUS_LED, 0);
    } // конец проверки таймаута отсечки
 } // конец функции processCutoff
 
 // Проверка потери связи (если пинги от пульта перестали приходить)
 void processTimeOut() {
    if ((millis() - pingTimeOutLastTime) > pingTimeout) {
      signalStatus = false;
      pingTimeOutLastTime = millis();
      
      if (currentState == STATE_NORMAL) {
        DEBUGln(F("[RADIO] Ping Timeout! No connection."));
        flashStatusLed(2); // Двойная вспышка - индикация потери связи
      }
      else if (currentState == STATE_CONFIG) { 
        DEBUGln(F("[STATE] Config Timeout (No Heartbeat) -> STATE_NORMAL"));
        currentState = STATE_NORMAL; updateStatusLed(false); 
      }
      else if (currentState == STATE_EXEC_CONFIG) { 
        DEBUGln(F("[STATE] Exec Config Timeout (No Heartbeat) -> STATE_NORMAL"));
        currentState = STATE_NORMAL; updateStatusLed(false); 
      } // конец ветвления состояний при таймауте
    } // конец проверки интервала таймаута
 } // конец функции processTimeOut
 
 // ======================= ОСНОВНЫЕ ФУНКЦИИ (SETUP & LOOP) =======================
 
 void setup() {
    // --- СНЯТИЕ ЗАМОРОЗКИ ПИНОВ ПОСЛЕ СНА ---
    gpio_hold_dis((gpio_num_t)PIN_VEXT);
    gpio_hold_dis((gpio_num_t)PIN_ADC_CTRL);
    gpio_deep_sleep_hold_dis();
    // ----------------------------------------
 
    // --- ОТКЛЮЧЕНИЕ RF-МОДЕМА НА СТАРТЕ ДЛЯ ЭКОНОМИИ ЭНЕРГИИ ---
    WiFi.mode(WIFI_OFF);
    // -----------------------------------------------------------
 
 #ifdef DEBUG_ENABLE
    Serial.begin(115200); 
    while (!Serial); 
 #endif
 
    DEBUGln(F("================================"));
    DEBUGln(F("=========== START RX v1.67 ==========="));
    
    DEBUGln(F("[STATE] Initializing GPIO pins..."));
    pinMode(PIN_REED, INPUT_PULLUP);
    pinMode(PIN_USER, INPUT_PULLUP); 
    pinMode(PIN_STATUS_LED, OUTPUT);
    digitalWrite(PIN_STATUS_LED, LOW);
 
    DEBUGln(F("[STATE] Loading NVS config..."));
    loadConfig();
 
    DEBUGln(F("[STATE] Running wake-up protection..."));
    runWakeUpProtection(PIN_REED);
    delay(2000);
 
    DEBUG(F("Work Channel/Address: ")); DEBUGln(workAddress);
    DEBUG(F("Battery Check Enabled: ")); DEBUGln(measurebattery ? "YES" : "NO");
    DEBUG(F("RX BIG LED Brightness: ")); DEBUGln(pwmledBrightness);
    DEBUG(F("RX Buzzer Volume: ")); DEBUGln(buzzerVolume);
    
    // Вывод параметров NVS
    DEBUG(F("Bat. Period (ms): ")); DEBUGln(batteryPeriod);
    DEBUG(F("Wake Hold/Rel (ms): ")); DEBUG(wakeUpHoldTime); DEBUG(F("/")); DEBUGln(wakeUpReleaseWindow);
    DEBUG(F("Stuck Sleep (ms): ")); DEBUGln(stuckSleepTime);
    DEBUG(F("Config TO (ms): ")); DEBUGln(configTimeout);
    DEBUG(F("Sleep LED (ms): ")); DEBUGln(sleepLedDuration);
    DEBUG(F("RX En. Big LED: ")); DEBUGln(enableBigLed ? "YES" : "NO");
    DEBUG(F("RX En. Buzzer: ")); DEBUGln(enableBuzzer ? "YES" : "NO");
    DEBUG(F("RX Cutoff (ms): ")); DEBUGln(cutoffTime);
    DEBUG(F("RX Ping TO (ms): ")); DEBUGln(pingTimeout);
    DEBUG(F("Max Power Limit: ")); DEBUGln(maxPower);
 
    DEBUGln(F("[STATE] ---> STATE_NORMAL (Boot)"));
 
    DEBUGln(F("[STATE] Powering up peripherals (VEXT/ADC)..."));
    pinMode(PIN_VEXT, OUTPUT); digitalWrite(PIN_VEXT, HIGH);     
    pinMode(PIN_ADC_CTRL, OUTPUT); digitalWrite(PIN_ADC_CTRL, HIGH); 
    pinMode(PIN_SIGNAL_BUZZERS, OUTPUT); pinMode(PIN_SIGNAL_LED, OUTPUT);
    pinMode(PIN_BATTERY_LED, OUTPUT); digitalWrite(PIN_BATTERY_LED, 0);
    
    analogWrite(PIN_SIGNAL_LED, 0); analogWrite(PIN_SIGNAL_BUZZERS, 0);
    delay(300);
 
    DEBUGln(F("[ACTION] Testing LEDs and Buzzer..."));
    updateStatusLed(true);
    if (enableBigLed) analogWrite(PIN_SIGNAL_LED, pwmledBrightness);
    if (enableBuzzer) analogWrite(PIN_SIGNAL_BUZZERS, buzzerVolume);
    delay(1000);
    updateStatusLed(false);
    analogWrite(PIN_SIGNAL_LED, 0); analogWrite(PIN_SIGNAL_BUZZERS, 0);  
    delay(1000);
 
    DEBUGln(F("[ACTION] Checking battery status..."));
    if (measurebattery) {
      isBatteryConnected = testBattery(); 
      if (isBatteryConnected) {
        DEBUGln(F("[ACTION] Battery connected. Showing voltage (2 times)."));
        processBattery(); 
        delay(500); 
        showBatteryVoltage(); 
        delay(2000); 
        showBatteryVoltage(); 
        delay(500);
      } else { 
        DEBUGln(F("[ACTION] No battery detected."));
        showNoBattery(); 
        delay(500); 
      } // конец ветвления индикации подключенной батареи
    } else {
      DEBUGln(F("[ACTION] Battery measurement disabled in config."));
    } // конец ветвления включения замеров батареи
 
    DEBUGln(F("[STATE] Initializing LoRa radio..."));
    SPI.begin(sckPin, misoPin, mosiPin, csPin);
    workFrequency = WORK_FREQUENCY + ( (workAddress % MAX_ADDRESS) * 200000 );
    DEBUG(F("[RADIO] LoRa Init on Frequency: ")); DEBUGln(workFrequency);
    
    int state = radio.begin(workFrequency / 1000000.0);
    if (state != RADIOLIB_ERR_NONE) {
      DEBUG(F("[RADIO] Init FAILED, code: ")); DEBUGln(state);
      while (true) { flashStatusLed(6); delay(4000); }
    } // конец проверки инициализации радио
 
    setLoRaParams();
    
    // Максимальная чувствительность приемника
    radio.setRxBoostedGainMode(true);
    
    radio.setDio1Action(setFlag);
    radio.startReceive();
 
    pingTimeOutLastTime = millis();
    
    // --- СНИЖЕНИЕ ЧАСТОТЫ ПРОЦЕССОРА ТОЛЬКО ПОСЛЕ ПОЛНОЙ ИНИЦИАЛИЗАЦИИ ---
    // Спасает стек ipc1 от переполнения на старте!
    setCpuFrequencyMhz(80);
    // ---------------------------------------------------------------------
    
    DEBUGln(F("[STATE] Setup complete"));
 } // конец функции setup
 
 void loop() {
    // Проверка, пришел ли пакет по воздуху
    checkReceive(); 
 
    // Исполнение пришедшей команды либо проверка таймаута соединения
    if (rcvCmd) processCommand(); 
    else processTimeOut(); 
 
    // Маршрутизация логики в зависимости от режима
    if (currentState == STATE_NORMAL) processCutoff();
    else if (currentState == STATE_CONFIG) processConfigLed();
    else if (currentState == STATE_EXEC_CONFIG) processExecConfigLed();
    
    processUserButton(); 
 
    // Периодический мониторинг заряда батареи
    EVERY_MS(batteryPeriod) {
      if (measurebattery && isBatteryConnected) processBattery();
    } // конец интервала проверки батареи
 
    // --- FREERTOS YIELD: Передача управления ОС для охлаждения процессора и экономии батареи ---
    delay(1); 
 } // конец функции loop

```

---

## File: .\src\RadioComm.cpp
```cpp
/**
 * @file RadioComm.cpp
 * @version 1.53
 * @brief Реализация радиосвязи SX1262 (RX)
 */
 #include "RadioComm.h"
 #include "Config.h"
 
 // Локальные макросы отладки
 #define DEBUG_ENABLE // Логирование выключено
 #ifdef DEBUG_ENABLE
 #define DEBUG(x) Serial.print(x)
 #define DEBUGln(x) Serial.println(x)
 #else
 #define DEBUG(x)
 #define DEBUGln(x)
 #endif
 
 extern const int sckPin = 9;
 extern const int misoPin = 11;
 extern const int mosiPin = 10;
 extern const int csPin = 8;
 extern const int resetPin = 12;
 extern const int irqPin = 14;
 extern const int busyPin = 13;
 
 SX1262 radio = new Module(csPin, irqPin, resetPin, busyPin);
 
 byte rcvAddress = 0;
 byte rcvCmd = 0;
 byte rcvData = 0;
 unsigned long workFrequency = WORK_FREQUENCY;
 
 unsigned long lastSendTime = 0;
 volatile bool receivedFlag = false;
 
//  // Список рабочих частот (каналов связи)
//  unsigned long workingFrequency[MAX_ADDRESS] = {
//     434000000, 434120000, 434240000, 433820000, 433700000, 433940000, 434030000,
//     434150000, 434270000, 433850000, 433730000, 433970000, 434060000, 434180000,
//     433880000, 433760000, 434090000, 434210000, 433910000, 433790000,
//  };
// теперь будет вычисляться по формуле: 434000000 + (адрес * 200000)
 #if defined(ESP8266) || defined(ESP32)
    ICACHE_RAM_ATTR
 #endif
 void setFlag(void) { 
    receivedFlag = true; 
 } // конец функции прерывания setFlag
 
 void setLoRaParams() {
    DEBUGln("[RADIO] setLoRaParams()");
    radio.setOutputPower(20);                     
    radio.setBandwidth(125.0);                    
    radio.setSpreadingFactor(8);                  
    radio.setCodingRate(5);                       
    radio.setPreambleLength(8);                   
    radio.setSyncWord(RADIOLIB_SX126X_SYNC_WORD_PRIVATE); 
 } // конец функции setLoRaParams
 
 // Отправка пакета-ответа пульту
 void transmitPacket(byte* payload, size_t size) {
    DEBUG(F("[RADIO] >>> TX Packet [Size: ")); DEBUG(size); DEBUG(F("]: "));
    for (size_t i = 0; i < size; i++) { DEBUG(payload[i]); DEBUG(F(" ")); }
    DEBUGln();
 
    int state = radio.transmit(payload, size);
    if (state != RADIOLIB_ERR_NONE) {
      DEBUG(F("[RADIO] >>> Transmit failed, code: ")); DEBUGln(state);
    } // конец проверки ошибки передачи
    
    lastSendTime = millis();
    pingTimeOutLastTime = lastSendTime; // Сброс таймера отсутствия связи
    receivedFlag = false; 
    radio.startReceive(); // Немедленный возврат к прослушиванию эфира
 } // конец функции transmitPacket
 
 void sendMessage(byte msgAddr, byte msgCmd, byte msgData) {
    byte payload[3] = {msgAddr, msgCmd, msgData}; 
    transmitPacket(payload, 3);                         
 } // конец функции sendMessage
 
 // Проверка прерывания: пришел ли пакет из эфира
 void checkReceive() {
    if (receivedFlag) {
      receivedFlag = false;
      byte payload[256];
      int state = radio.readData(payload, sizeof(payload));
      if (state == RADIOLIB_ERR_NONE) {
        onReceive(payload, radio.getPacketLength());           
      } // конец проверки успешного приема
      radio.startReceive();                       
    } // конец проверки флага прерывания
 } // конец функции checkReceive
 
 // Обработка входящего пакета и передача команды в стейт-машину
 void onReceive(byte* payload, int packetSize) {
    DEBUG(F("[RADIO] <<< RX Packet [Size: ")); DEBUG(packetSize); DEBUG(F("]: "));
    for (int i = 0; i < packetSize; i++) { DEBUG(payload[i]); DEBUG(F(" ")); }
    DEBUGln();
 
    // Адресный фильтр: игнорируем чужие пульты
    rcvAddress = payload[0];
    if (rcvAddress != workAddress) {
      DEBUGln(F("\t[!] Ignored: Wrong address"));
      return;
    } // конец проверки адреса
 
    // Стандартный пакет управления
    if (packetSize == 3) {
      rcvCmd = payload[1];
      rcvData = payload[2];
      
      if (rcvCmd == CMD_REBOOT) {
        DEBUGln(F("[ACTION] !!! CMD_REBOOT RECEIVED. Restarting in 500ms !!!"));
        delay(500);
        ESP.restart();
      } // конец обработки команды перезагрузки
    } 
    // Длинный пакет: Синхронизация структуры настроек по воздуху
    else if (packetSize == (sizeof(ConfigPacket) + 2) && payload[1] == CMD_SYNC_CONFIG) {
      DEBUGln(F("[RADIO] <<< Received Config Struct from TX!"));
      
      ConfigPacket newSettings;
      memcpy(&newSettings, &payload[2], sizeof(ConfigPacket));
      
      saveConfigFromPacket(&newSettings);
      
      DEBUGln(F("[RADIO] Replying with CMD_SYNC_CONFIG_OK"));
      sendMessage(workAddress, CMD_SYNC_CONFIG_OK, 1);
      
      rcvCmd = 0; 
    } 
    else {
      DEBUGln(F("\t[!] Invalid packet size or command!"));
    } // конец проверки длины пакета
 } // конец функции onReceive
```

---

## File: .\src\RadioComm.h
```cpp
/**
 * @file RadioComm.h
 * @version 1.53
 * @brief Модуль радиосвязи SX1262 и протокол (RX)
 * Описание: Слушает эфир, фильтрует пакеты по адресу и транслирует команды в main.cpp.
 */
 #ifndef RADIOCOMM_H
 #define RADIOCOMM_H
 
 #include <Arduino.h>
 #include <RadioLib.h>
 #include <SPI.h>
 
 // --- Макросы команд (Протокол связи v1.53) ---
 #define CMD_SIGNAL         208  // Сигнал нажатия кнопки (Action!)
 #define CMD_SIGNAL_OK      209
 #define CMD_PING           212  // Пинг от пульта
 #define CMD_PING_OK        213
 #define CMD_SLEEP          214  // Приказ уснуть
 #define CMD_SLEEP_OK       215
 #define CMD_CONFIG         216  // Переход в режим настройки Wi-Fi
 #define CMD_CONFIG_OK      217
 #define CMD_NORMAL_MODE    218  // Возврат в рабочий режим
 #define CMD_NORMAL_MODE_OK 219
 #define CMD_SYNC_CONFIG    220  // Прием длинного пакета с настройками
 #define CMD_SYNC_CONFIG_OK 221
 #define CMD_REBOOT         222  // Перезагрузка
 #define CMD_EXEC_CONFIG    223  // Переход в режим выбора свето/вибро
 #define CMD_EXEC_CONFIG_OK 224
 #define CMD_CYCLE_EXEC     225  // Смена свето/вибро по кругу
 #define CMD_CYCLE_EXEC_OK  226
 
 #define WORK_FREQUENCY 434E6
 #define MAX_ADDRESS 81
 
 // --- Пины и объекты ---
 extern const int sckPin;
 extern const int misoPin;
 extern const int mosiPin;
 extern const int csPin;
 extern const int resetPin;
 extern const int irqPin;
 extern const int busyPin;
 
 extern SX1262 radio;
 
 // --- Переменные радиообмена ---
 extern byte rcvAddress;
 extern byte rcvCmd;
 extern byte rcvData;
 extern unsigned long workFrequency;
 extern unsigned long lastSendTime;
 extern volatile bool receivedFlag;
 //extern unsigned long workingFrequency[MAX_ADDRESS];
 
 // Внешние переменные из main.cpp
 extern unsigned long pingTimeOutLastTime;
 
 // --- Прототипы ---
 void setFlag(void);
 void setLoRaParams();
 void transmitPacket(byte* payload, size_t size);
 void sendMessage(byte msgAddr, byte msgCmd, byte msgData);
 void checkReceive();
 void onReceive(byte* payload, int packetSize);
 
 #endif
```

---

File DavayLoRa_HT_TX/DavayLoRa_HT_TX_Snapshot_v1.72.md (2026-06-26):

# Project: DavayLoRa_HT_TX Snapshot V1.72

## File: .\src\Battery.cpp
```cpp
/**
 * @file Battery.cpp
 * @version 1.53
 * @brief Реализация подсистемы питания (TX)
 */
 #include "Battery.h"

 // Локальные макросы отладки
 #define DEBUG_ENABLE // Логирование выключено
 #ifdef DEBUG_ENABLE
 #define DEBUG(x) Serial.print(x)
 #define DEBUGln(x) Serial.println(x)
 #else
 #define DEBUG(x)
 #define DEBUGln(x)
 #endif
 
 bool isBatteryConnected = false;
 
 // Проверяет, подключена ли батарея, делая несколько замеров
 bool testBattery() { return batteryVoltageOK(5); } // конец функции testBattery
 
 bool batteryVoltageOK(byte tries) {
    float minV = 5.0, maxV = 0.0;
    for (byte i = 0; i < tries; i++) {
      float currentVBat = batteryVoltage();
      if (currentVBat < minV) minV = currentVBat; 
      if (currentVBat > maxV) maxV = currentVBat; 
      delay(150);
    } // конец цикла замеров
    return (maxV - minV) <= 0.05;
 } // конец функции batteryVoltageOK
 
 // Чтение реального напряжения через внутренний АЦП и делитель
 float batteryVoltage() {
    digitalWrite(PIN_ADC_CTRL, LOW); delay(10);
    float measuredvbat = analogRead(PIN_BATTERY_INTERNAL);
    digitalWrite(PIN_ADC_CTRL, HIGH);
    measuredvbat *= 3.3 * HELTEC_BATTERY_MULTIPLIER / 4095.0;
    return measuredvbat;
 } // конец функции batteryVoltage
 
 // Индикация заряда (от 1 до 5 вспышек в зависимости от напряжения)
 void showBatteryVoltage() {
    float voltage = batteryVoltage();
    if (voltage > BATTERY_VOLTAGE_1) flashBatteryLEDOnce(); 
    if (voltage > BATTERY_VOLTAGE_2) flashBatteryLEDOnce(); 
    if (voltage > BATTERY_VOLTAGE_3) flashBatteryLEDOnce(); 
    if (voltage > BATTERY_VOLTAGE_4) flashBatteryLEDOnce(); 
    if (voltage > BATTERY_VOLTAGE_5) flashBatteryLEDOnce(); 
 } // конец функции showBatteryVoltage
 
 // Индикация отсутствия батареи (длинная вспышка)
 void showNoBattery() { 
    digitalWrite(PIN_BATTERY_LED, 1); delay(2000); digitalWrite(PIN_BATTERY_LED, 0); delay(250); 
 } // конец функции showNoBattery
 
 void flashBatteryLEDOnce() { updateStatusLed(true); delay(250); updateStatusLed(false); delay(250); } // конец функции flashBatteryLEDOnce
 
 // Регулярная проверка. Если батарея села - уходим в сон
 void processBattery() { if (batteryVoltage() < BATTERY_MIN_VOLTAGE) stopWorking(); } // конец функции processBattery
 
 void stopWorking() { 
    DEBUGln(F("[STATE] BATTERY DEAD! Stopping..."));
    enterDeepSleep(); 
 } // конец функции stopWorking
```

---

## File: .\src\Battery.h
```cpp
/**
 * @file Battery.h
 * @version 1.53
 * @brief Подсистема питания и контроля батареи (TX)
 * Описание: Отвечает за проверку напряжения Li-Po аккумулятора и защиту от глубокого разряда.
 */
 #ifndef BATTERY_H
 #define BATTERY_H
 
 #include <Arduino.h>
 
 // --- Пороги напряжений ---
 #define BATTERY_MIN_VOLTAGE 3.5
 #define BATTERY_VOLTAGE_1 3.5
 #define BATTERY_VOLTAGE_2 3.6
 #define BATTERY_VOLTAGE_3 3.8
 #define BATTERY_VOLTAGE_4 3.9
 #define BATTERY_VOLTAGE_5 4.0
 
 // --- Пины и константы батареи ---
 #define PIN_BATTERY_LED 35     
 #define PIN_BATTERY_INTERNAL 1 
 #define PIN_ADC_CTRL 37        
 #define HELTEC_BATTERY_MULTIPLIER 4.9
 
 extern bool isBatteryConnected;
 
 // Внешние зависимости (функции, которые остались в main.cpp)
 extern void updateStatusLed(bool ledStatus);
 extern void enterDeepSleep();
 
 // Прототипы функций
 bool testBattery();
 bool batteryVoltageOK(byte tries);
 float batteryVoltage();
 void showBatteryVoltage();
 void showNoBattery();
 void flashBatteryLEDOnce();
 void processBattery();
 void stopWorking();
 
 #endif
```

---

## File: .\src\Config.cpp
```cpp
/**
 * @file Config.cpp
 * @version 1.64
 * @brief Реализация загрузки и сохранения настроек (TX)
 */
 #include "Config.h"

 // Локальные макросы отладки
 #define DEBUG_ENABLE // Логирование выключено
 #ifdef DEBUG_ENABLE
 #define DEBUG(x) Serial.print(x)
 #define DEBUGln(x) Serial.println(x)
 #else
 #define DEBUG(x)
 #define DEBUGln(x)
 #endif
 
 ConfigPacket rxSettings;
 Preferences preferences; // Объект для работы с NVS (сохранение настроек)
 
 byte workAddress = 0;                 
 bool measurebattery = true;           
 unsigned long batteryPeriod = 300000;    
 unsigned long wakeUpHoldTime = 2000;     
 unsigned long wakeUpReleaseWindow = 2000; 
 unsigned long stuckSleepTime = 10000; 
 unsigned long configTimeout = 600000; 
 unsigned long sleepLedDuration = 2000;   
 int maxPower = 20; // Максимальная мощность по умолчанию
 
 int pwmledBrightness = 35;            
 int fbledBrightness = 255;            
 unsigned long pingTimeout = 3000;     
 unsigned long bigTimeout = 3600000;   
 unsigned long execTimeout = 30000;    
 bool dynamicPower = true; // Адаптивная мощность включена
 int minPower = -9;        // Аппаратный минимум SX1262
 int servicePower = 18;    // Комфортная мощность для ближней связи
 
 unsigned long pingTimeoutRX = 9000;   
 
 // Чтение настроек из памяти при загрузке системы
 void loadConfig() {
    DEBUGln(F("--- Loading config from NVS ---"));
    preferences.begin("davaylora", false); 
    
    workAddress = preferences.getUChar("workAddress", 4);
    measurebattery = preferences.getBool("measureBat", true);
    batteryPeriod = preferences.getULong("batPeriod", 300000);
    wakeUpHoldTime = preferences.getULong("wkUpHold", 2000);
    wakeUpReleaseWindow = preferences.getULong("wkUpRel", 2000);
    stuckSleepTime = preferences.getULong("stuckSleep", 10000);
    configTimeout = preferences.getULong("confTo", 600000);
    sleepLedDuration = preferences.getULong("sleepLedDur", 2000);
    maxPower = preferences.getInt("maxPwr", 20);
    
    pwmledBrightness = preferences.getInt("bigLedBright", 35);
    fbledBrightness = preferences.getInt("fbLedBright", 255);
    pingTimeout = preferences.getULong("pingTimeout", 3000);
    bigTimeout = preferences.getULong("bigTimeout", 3600000);
    execTimeout = preferences.getULong("execTo", 30000); 
    dynamicPower = preferences.getBool("dynPwr", true);
    minPower = preferences.getInt("minPwr", -9);
    servicePower = preferences.getInt("srvPwr", 18);
    
    pingTimeoutRX = preferences.getULong("pingRx", 9000); 
    rxSettings.rxEnableBigLed = preferences.getBool("rxEnBigLed", true);
    rxSettings.rxPwmledBrightness = preferences.getInt("rxBigBright", 35);
    rxSettings.rxEnableBuzzer = preferences.getBool("rxEnBuzzer", false);
    rxSettings.rxBuzzerVolume = preferences.getInt("rxBuzVol", 255);
    rxSettings.rxCutoffTime = preferences.getULong("rxCutoff", 2000);
    rxSettings.maxPower = maxPower; // Синхронизация структуры
 
    preferences.end();
    DEBUGln(F("Config loaded."));
 } // конец функции loadConfig
 
 // Сохранение новых настроек после изменения их через Wi-Fi портал
 void saveConfig() {
    DEBUGln(F("--- Saving config to NVS ---"));
    preferences.begin("davaylora", false);
    
    preferences.putUChar("workAddress", workAddress);
    preferences.putBool("measureBat", measurebattery);
    preferences.putULong("batPeriod", batteryPeriod);
    preferences.putULong("wkUpHold", wakeUpHoldTime);
    preferences.putULong("wkUpRel", wakeUpReleaseWindow);
    preferences.putULong("stuckSleep", stuckSleepTime);
    preferences.putULong("confTo", configTimeout);
    preferences.putULong("sleepLedDur", sleepLedDuration);
    preferences.putInt("maxPwr", maxPower);
    
    preferences.putInt("bigLedBright", pwmledBrightness);
    preferences.putInt("fbLedBright", fbledBrightness);
    preferences.putULong("pingTimeout", pingTimeout);
    preferences.putULong("bigTimeout", bigTimeout);
    preferences.putULong("execTo", execTimeout); 
    preferences.putBool("dynPwr", dynamicPower);
    preferences.putInt("minPwr", minPower);
    preferences.putInt("srvPwr", servicePower);
    
    preferences.putULong("pingRx", pingTimeoutRX); 
    preferences.putBool("rxEnBigLed", rxSettings.rxEnableBigLed);
    preferences.putInt("rxBigBright", rxSettings.rxPwmledBrightness);
    preferences.putBool("rxEnBuzzer", rxSettings.rxEnableBuzzer);
    preferences.putInt("rxBuzVol", rxSettings.rxBuzzerVolume);
    preferences.putULong("rxCutoff", rxSettings.rxCutoffTime);
    
    preferences.end();
    
    // Синхронизируем структуру перед возможной отправкой
    rxSettings.maxPower = maxPower;
    
    DEBUGln(F("Config saved."));
 } // конец функции saveConfig
```

---

## File: .\src\Config.h
```cpp
/**
 * @file Config.h
 * @version 1.64
 * @brief Глобальные настройки и работа с энергонезависимой памятью NVS (TX)
 * Описание: Хранит все пользовательские настройки (таймауты, яркости, адреса, настройки мощности).
 */
 #ifndef CONFIG_H
 #define CONFIG_H
 
 #include <Arduino.h>
 #include <Preferences.h>
 
 // Структура пакета настроек для передачи на приемник (RX)
 #pragma pack(push, 1)
 struct ConfigPacket {
    byte workAddress;
    bool measurebattery;
    unsigned long batteryPeriod;
    unsigned long wakeUpHoldTime;
    unsigned long wakeUpReleaseWindow;
    unsigned long stuckSleepTime;
    unsigned long configTimeout;
    unsigned long sleepLedDuration;
    
    bool rxEnableBigLed;
    int rxPwmledBrightness;
    bool rxEnableBuzzer;
    int rxBuzzerVolume;
    unsigned long rxCutoffTime;
    unsigned long pingTimeoutRX;
    int maxPower; // Ограничение максимальной мощности (0-22 дБм)
 };
 #pragma pack(pop)
 
 extern ConfigPacket rxSettings;
 extern Preferences preferences;
 
 // --- Системные и общие переменные ---
 extern byte workAddress;                 
 extern bool measurebattery;           
 extern unsigned long batteryPeriod;    
 extern unsigned long wakeUpHoldTime;     
 extern unsigned long wakeUpReleaseWindow; 
 extern unsigned long stuckSleepTime; 
 extern unsigned long configTimeout; 
 extern unsigned long sleepLedDuration;   
 extern int maxPower; // Максимальная мощность (для обеих плат)
 
 // --- Настройки пульта (TX) ---
 extern int pwmledBrightness;            
 extern int fbledBrightness;            
 extern unsigned long pingTimeout;     
 extern unsigned long bigTimeout;   
 extern unsigned long execTimeout;    
 extern bool dynamicPower; // Включение адаптивной мощности
 extern int minPower;      // Минимальный порог мощности для адаптации (-9 - 0)
 extern int servicePower;  // Мощность для сервисных команд (0 - 22)
 
 // --- Настройки приемника (для синхронизации) ---
 extern unsigned long pingTimeoutRX;   
 
 // Прототипы
 void loadConfig();
 void saveConfig();
 
 #endif
```

---

## File: .\src\main.cpp
```cpp
/**
 * @file main.cpp (TX) (TEST)
 * @version 1.72 Внедрена вычисляемая рабочая частота и число каналов 81
 * @brief Прошивка передатчика (Transmitter) для проекта DavayLoRa на базе Heltec Wireless Stick Lite V3
 * Описание: Ядро стейт-машины, логика переключения режимов и опроса кнопок.
 */

 #include <Arduino.h>
 #include <esp_sleep.h>
 #include <driver/rtc_io.h>
 #include <driver/gpio.h> // Добавлено для функций заморозки пинов (gpio_hold)
 #include <WiFi.h>        // Добавлено для принудительного отключения модема на старте
 
 #include "Battery.h" 
 #include "Config.h"  
 #include "WebPortal.h" 
 #include "RadioComm.h" 
 
 // ======================= АППАРАТНАЯ КОНФИГУРАЦИЯ =======================
 #define PIN_BUTTON 7           
 #define PIN_FB_LED 35          
 #define PIN_BIG_LED 41         
 #define PIN_USER 0             
 #define PIN_VEXT 36            
 
 // ======================= ГЛОБАЛЬНЫЕ ПЕРЕМЕННЫЕ И МАКРОСЫ =======================
 
 // Локальные макросы отладки
 #define DEBUG_ENABLE // Логирование ВКЛЮЧЕНО
 #ifdef DEBUG_ENABLE
 #define DEBUG(x) Serial.print(x)
 #define DEBUGln(x) Serial.println(x)
 #else
 #define DEBUG(x)
 #define DEBUGln(x)
 #endif
 
 #define EVERY_MS(x) \
    static uint32_t tmr;\
    bool flg = millis() - tmr >= (x);\
    if (flg) { tmr = millis(); }\
    if (flg)
 
 #define PING_FLASH 100             
 #define DEBOUNCE_TIME 100          
 
 unsigned long lastButtonTime;
 
 bool currButtonState;
 bool prevButtonState;
 bool buttonPressedFirstTime;
 
 unsigned long pingTimer;
 unsigned long pingFlashTimer;
 bool pingFlash;
 
 // --- ПЕРЕМЕННЫЕ АДАПТАЦИИ МОЩНОСТИ ---
 int currentTxPower = 22;      // Текущая мощность (перезаписывается при старте из Config)
 const int targetRssi = -95;   // Целевой уровень сигнала на стороне RX
 // --------------------------------------
 
 enum SystemState {
    STATE_NORMAL,          // Рабочий режим (передача сигналов)
    STATE_PREPARATION,     // Режим подготовки (ожидание серии кликов)
    STATE_CONFIG_STANDBY,  // Ожидание запуска Wi-Fi
    STATE_EXEC_CONFIG      // Режим переключения типа сигнала на лету
 };
 SystemState currentState = STATE_NORMAL;
 
 unsigned long buttonPressStartTime = 0; 
 unsigned long prepModeTimer = 0;        
 byte prepClickCount = 0;
 unsigned long lastPrepClickTime = 0;
 
 byte configClickCount = 0;
 unsigned long lastConfigClickTime = 0;
 
 bool configBlinkActive = false;
 unsigned long configBlinkStartTime = 0; 
 
 byte execClickCount = 0;
 unsigned long lastExecClickTime = 0;
 
 bool execBlinkActive = false;
 unsigned long execBlinkStartTime = 0; 
 
 unsigned long execModeTimer = 0; 
 
 // --- ПРОТОТИПЫ ---
 void updateStatusLed(bool ledStatus);
 void updateBIGLed(bool ledStatus);
 void flashStatusLed(byte times);
 void processConfigLed();
 void processExecConfigLed();
 void enterDeepSleep();
 void runWakeUpProtection(uint8_t wakeupPin);
 void sleepSystem();
 void processButton();
 void processUserButton();
 void processPreparationMode();
 void processConfigStandby();
 void processExecConfigStandby();
 void processPing();
 
 // ======================= ИНДИКАЦИЯ (LED) =======================
 
 void updateStatusLed(bool ledStatus) { 
    static int lastBrightness = -1;
    int newBrightness = ledStatus ? fbledBrightness : 0;
    
    if (lastBrightness != newBrightness) {
      analogWrite(PIN_FB_LED, newBrightness);
      lastBrightness = newBrightness;
    } // конец защиты от спама analogWrite
 } // конец функции updateStatusLed
 
 void updateBIGLed(bool ledStatus) { 
    static int lastBigBrightness = -1;
    int newBrightness = ledStatus * pwmledBrightness;
    
    if (lastBigBrightness != newBrightness) {
      analogWrite(PIN_BIG_LED, newBrightness); 
      lastBigBrightness = newBrightness;
    } // конец защиты от спама analogWrite
 } // конец функции updateBIGLed
 
 void flashStatusLed(byte times) {
    for (int i = 0; i < times; i++) {
      updateStatusLed(true); delay(100); updateStatusLed(false); delay(200);
    } // конец цикла вспышек
 } // конец функции flashStatusLed
 
 void processConfigLed() {
    if (!configBlinkActive) return;
    unsigned long elapsed = millis() - configBlinkStartTime;
    if (elapsed < 100) updateStatusLed(true); 
    else if (elapsed < 200) updateStatusLed(false); 
    else if (elapsed < 300) updateStatusLed(true); 
    else if (elapsed < 400) updateStatusLed(false); 
    else if (elapsed < 500) updateStatusLed(true); 
    else { updateStatusLed(false); configBlinkActive = false; }
 } // конец функции processConfigLed
 
 void processExecConfigLed() {
    if (!execBlinkActive) return;
    unsigned long elapsed = millis() - execBlinkStartTime;
    if (elapsed < 100) updateStatusLed(true); 
    else if (elapsed < 200) updateStatusLed(false); 
    else if (elapsed < 300) updateStatusLed(true); 
    else { updateStatusLed(false); execBlinkActive = false; }
 } // конец функции processExecConfigLed
 
 // ======================= УПРАВЛЕНИЕ ПИТАНИЕМ И СНОМ =======================
 
 void enterDeepSleep() {
    DEBUGln(F("[STATE] ---> ENTERING DEEP SLEEP"));
    if (isWifiActive) stopWiFiPortal(); 
    
    radio.sleep();
    SPI.end();
    
    // Симметричное отключение пинов SPI, как в RX, для устранения паразитных утечек тока
    pinMode(csPin, INPUT); pinMode(mosiPin, INPUT); pinMode(misoPin, INPUT);
    pinMode(sckPin, INPUT); pinMode(resetPin, INPUT); pinMode(busyPin, INPUT);
    pinMode(irqPin, INPUT);
    
    pinMode(PIN_VEXT, OUTPUT); digitalWrite(PIN_VEXT, HIGH); 
    pinMode(PIN_ADC_CTRL, OUTPUT); digitalWrite(PIN_ADC_CTRL, HIGH);
    
    // --- ИДЕАЛЬНЫЙ СОН: Заморозка пинов для исключения плавающих уровней ---
    gpio_hold_en((gpio_num_t)PIN_VEXT);
    gpio_hold_en((gpio_num_t)PIN_ADC_CTRL);
    gpio_deep_sleep_hold_en();
    // -----------------------------------------------------------------------
 
    pinMode(PIN_FB_LED, OUTPUT); digitalWrite(PIN_FB_LED, LOW);
    pinMode(PIN_BIG_LED, OUTPUT); digitalWrite(PIN_BIG_LED, LOW);
    pinMode(PIN_BATTERY_LED, OUTPUT); digitalWrite(PIN_BATTERY_LED, LOW);
    
    rtc_gpio_pullup_en((gpio_num_t)PIN_BUTTON);
    rtc_gpio_pulldown_dis((gpio_num_t)PIN_BUTTON);
    
    // --- ИСПРАВЛЕНИЕ БАГА: Защита от бесконечного просыпания при зажатой кнопке ---
    if (digitalRead(PIN_BUTTON) == LOW) {
      DEBUGln(F("[STATE] Button is STUCK. Sleeping with timer..."));
      esp_sleep_enable_timer_wakeup(stuckSleepTime * 1000ULL);
    } else {
      DEBUGln(F("[STATE] Normal sleep. Wakeup on EXT0 (Button). Good night!"));
      esp_sleep_enable_ext0_wakeup((gpio_num_t)PIN_BUTTON, 0);
    }
    // ------------------------------------------------------------------------------
 
    esp_deep_sleep_start();
 } // конец функции enterDeepSleep
 
 void runWakeUpProtection(uint8_t wakeupPin) {
    esp_sleep_wakeup_cause_t wakeup_reason = esp_sleep_get_wakeup_cause();
    if (wakeup_reason == ESP_SLEEP_WAKEUP_TIMER) enterDeepSleep(); 
    
    if (wakeup_reason == ESP_SLEEP_WAKEUP_EXT0) {
      DEBUGln(F("[STATE] Woke up. Checking protection..."));
      updateStatusLed(true);
      unsigned long startHold = millis();
      while (millis() - startHold < wakeUpHoldTime) {
        if (digitalRead(wakeupPin) == HIGH) { 
          updateStatusLed(false); enterDeepSleep(); 
        } // конец проверки отпускания
        delay(10);
      } // конец цикла удержания
      
      unsigned long startReleaseWindow = millis();
      bool releasedInWindow = false;
      while (millis() - startReleaseWindow < wakeUpReleaseWindow) {
        updateStatusLed((millis() % 200) < 100); 
        if (digitalRead(wakeupPin) == HIGH) { 
          releasedInWindow = true; break; 
        } // конец проверки отпускания в окне
        delay(10);
      } // конец цикла окна отпускания
      
      if (!releasedInWindow) { 
        updateStatusLed(false); enterDeepSleep(); 
      } // конец условия ошибки просыпания
      updateStatusLed(false); 
    } // конец условия просыпания от кнопки
 } // конец функции runWakeUpProtection
 
 void sleepSystem() {
    DEBUGln(F("[ACTION] Sending Centralized SLEEP Command"));
    currentTxPower = servicePower; 
    radio.setOutputPower(currentTxPower);
    DEBUG(F("[RADIO] Send SLEEP (Power: ")); DEBUG(currentTxPower); DEBUGln(F(" dBm)"));
    commSession(CMD_SLEEP, 1, CMD_SLEEP_OK, 500, WORK_COMM_ATTEMPTS);
    
    updateStatusLed(true); delay(sleepLedDuration); updateStatusLed(false);
    enterDeepSleep();
 } // конец функции sleepSystem
 
 // ======================= ОБРАБОТКА ВВОДА (КНОПКИ) =======================
 
 void processButton() {
    prevButtonState = currButtonState;
    currButtonState = !digitalRead(PIN_BUTTON); 
    
    if (prevButtonState != currButtonState) {
      lastButtonTime = millis();
      
      if (currButtonState) { // Нажата
        DEBUGln(F("[ACTION] Main Button PRESSED"));
        if (currentState == STATE_NORMAL) {
          buttonPressStartTime = millis(); pingTimer = millis(); buttonPressedFirstTime = true;
          
          // Передача сигнала "ACTION!" на максимальной мощности
          currentTxPower = maxPower; 
          radio.setOutputPower(currentTxPower);
          DEBUG(F("[RADIO] Send ACTION (Power: ")); DEBUG(currentTxPower); DEBUGln(F(" dBm)"));
          if (commSession(CMD_SIGNAL, 1, CMD_SIGNAL_OK, 300, WORK_COMM_ATTEMPTS)) {
            updateStatusLed(true); updateBIGLed(true);    
            DEBUG(F("[RADIO] RX RSSI: ")); DEBUGln(radio.getRSSI());
          } else { updateBIGLed(false); flashStatusLed(2); }
        } else if (currentState == STATE_PREPARATION) {
          prepClickCount++; lastPrepClickTime = millis(); prepModeTimer = millis(); 
        } else if (currentState == STATE_CONFIG_STANDBY) {
          configClickCount++; lastConfigClickTime = millis();
        } else if (currentState == STATE_EXEC_CONFIG) {
          execClickCount++; lastExecClickTime = millis(); execModeTimer = millis(); 
        } // конец ветвления по состояниям
      } else { // Отпущена
        DEBUGln(F("[ACTION] Main Button RELEASED"));
        if (currentState == STATE_NORMAL) {
          // Отмена сигнала "ACTION!" на максимальной мощности
          currentTxPower = maxPower;
          radio.setOutputPower(currentTxPower);
          sendMessage(CMD_SIGNAL, false); updateStatusLed(false); updateBIGLed(false);
        } // конец условия для нормального режима
      } // конец условия проверки нажатия
    } // конец условия изменения состояния
 } // конец функции processButton
 
 void processUserButton() {
    static unsigned long userButtonTimer = 0;
    static bool prevUserState = HIGH;
    bool currUserState = digitalRead(PIN_USER);
    
    // Отслеживание физического нажатия и отпускания кнопки
    if (currUserState != prevUserState) {
      if (currUserState == LOW) {
        DEBUGln(F("[ACTION] USER Button PRESSED"));
        userButtonTimer = millis();
      } else {
        DEBUGln(F("[ACTION] USER Button RELEASED"));
        userButtonTimer = 0;
      }
      prevUserState = currUserState;
    } // конец отслеживания состояний
    
    // Таймер долгого удержания (5 секунд)
    if (currUserState == LOW && userButtonTimer > 0) {
      if (millis() - userButtonTimer > 5000) { 
        DEBUGln(F("[ACTION] USER button held 5s -> Local Sleep"));
        sleepSystem(); 
        userButtonTimer = 0; // Сброс таймера для предотвращения спама
      } // конец условия зажатия 5 сек
    } // конец проверки зажатия
 } // конец функции processUserButton
 
 // ======================= СТЕЙТ-МАШИНА И БИЗНЕС-ЛОГИКА =======================
 
 // Режим подготовки. Ожидает определенное количество кликов для перехода в другие режимы.
 void processPreparationMode() {
    EVERY_MS(166) {
      static bool prepLedState = false;
      prepLedState = !prepLedState;
      updateStatusLed(prepLedState);
    } // конец интервала мигания
 
    // Проверка завершения ввода серии кликов
    if (prepClickCount > 0 && (millis() - lastPrepClickTime > 600)) {
      currentTxPower = servicePower;
      radio.setOutputPower(currentTxPower);
      if (prepClickCount == 2) { 
        // 2 клика: Выключение приборов (Сон)
        sleepSystem(); 
      } else if (prepClickCount == 3) {
        // 3 клика: Смена типа сигнала актеру (свет/вибро)
        if (commSession(CMD_EXEC_CONFIG, 1, CMD_EXEC_CONFIG_OK, 500, WORK_COMM_ATTEMPTS)) {
          DEBUGln(F("[STATE] ---> STATE_EXEC_CONFIG"));
          currentState = STATE_EXEC_CONFIG; execModeTimer = millis(); 
          execBlinkActive = true; execBlinkStartTime = millis(); execClickCount = 0;
        }
      } else if (prepClickCount == 4) {
        // 4 клика: Полная настройка через телефон (Wi-Fi Портал)
        if (commSession(CMD_CONFIG, 1, CMD_CONFIG_OK, 500, WORK_COMM_ATTEMPTS)) {
          DEBUGln(F("[STATE] ---> STATE_CONFIG_STANDBY"));
          currentState = STATE_CONFIG_STANDBY; pingTimer = millis();
          configBlinkActive = true; configBlinkStartTime = millis(); configClickCount = 0;
        }
      } else {
        DEBUGln(F("[STATE] ---> STATE_NORMAL (Invalid clicks)"));
        currentState = STATE_NORMAL; updateStatusLed(false);
      } // конец разбора количества кликов
      prepClickCount = 0; 
    } // конец условия окончания кликов
 
    // Если пользователь ничего не нажал в течение 10 секунд - возврат в рабочий режим
    if (millis() - prepModeTimer > 10000 && currentState == STATE_PREPARATION) {
      DEBUGln(F("[STATE] Prep mode timeout -> Exit to STATE_NORMAL"));
      currentState = STATE_NORMAL; updateStatusLed(false);
    } // конец условия таймаута режима подготовки
 } // конец функции processPreparationMode
 
 // Ожидание в режиме настройки (до включения Wi-Fi)
 void processConfigStandby() {
    processConfigLed();
 
    if (configClickCount > 0 && (millis() - lastConfigClickTime > 600)) {
      if (configClickCount == 2) {
        // 2 клика: Возврат в рабочий режим
        if (isWifiActive) stopWiFiPortal();
        currentTxPower = servicePower;
        radio.setOutputPower(currentTxPower);
        commSession(CMD_NORMAL_MODE, 1, CMD_NORMAL_MODE_OK, 500, WORK_COMM_ATTEMPTS);
        DEBUGln(F("[STATE] ---> STATE_NORMAL (Exited Config via button)"));
        currentState = STATE_NORMAL; updateStatusLed(false);
      } else if (configClickCount == 1) { 
        // 1 клик: Активация точки доступа Wi-Fi
        if (!isWifiActive) startWiFiPortal(); 
      } // конец разбора кликов настройки
      configClickCount = 0;
    } // конец условия обработки кликов
 
    // Keep-alive для удержания приемника в режиме настройки
    if ((millis() - pingTimer) > pingTimeout) {
      currentTxPower = servicePower;
      radio.setOutputPower(currentTxPower);
      if (commSession(CMD_CONFIG, 1, CMD_CONFIG_OK, 500, WORK_COMM_ATTEMPTS)) {
        configBlinkActive = true; configBlinkStartTime = millis(); 
      } else {
        DEBUGln(F("[ERROR] Config Keepalive Failed! -> Exit to STATE_NORMAL"));
        if (isWifiActive) stopWiFiPortal(); 
        currentState = STATE_NORMAL; updateStatusLed(false); flashStatusLed(2); 
      } // конец условия отсутствия ответа от RX
      pingTimer = millis(); 
    } // конец проверки интервала пинга
 } // конец функции processConfigStandby
 
 // Ожидание в режиме переключения исполнительных устройств
 void processExecConfigStandby() {
    processExecConfigLed();
 
    if (millis() - execModeTimer > execTimeout) {
      DEBUGln(F("[STATE] Exec Config Inactivity Timeout -> Exit to STATE_NORMAL"));
      currentTxPower = servicePower;
      radio.setOutputPower(currentTxPower);
      commSession(CMD_NORMAL_MODE, 1, CMD_NORMAL_MODE_OK, 500, WORK_COMM_ATTEMPTS);
      currentState = STATE_NORMAL; updateStatusLed(false); execClickCount = 0;
    } // конец условия таймаута бездействия пользователя
 
    if (execClickCount > 0 && (millis() - lastExecClickTime > 600)) {
      currentTxPower = servicePower;
      radio.setOutputPower(currentTxPower);
      if (execClickCount == 2) {
        // 2 клика: Выход и сохранение
        commSession(CMD_NORMAL_MODE, 1, CMD_NORMAL_MODE_OK, 500, WORK_COMM_ATTEMPTS);
        DEBUGln(F("[STATE] ---> STATE_NORMAL (Exited Exec Config via button)"));
        currentState = STATE_NORMAL; updateStatusLed(false);
      } else if (execClickCount == 1) {
        // 1 клик: Цикличное переключение режимов света/вибро на приемнике
        if (commSession(CMD_CYCLE_EXEC, 1, CMD_CYCLE_EXEC_OK, 500, WORK_COMM_ATTEMPTS)) {
           rxSettings.rxEnableBigLed = (rcvData & 0x01);
           rxSettings.rxEnableBuzzer = (rcvData & 0x02) >> 1;
           saveConfig();
        } else { flashStatusLed(2); } // конец условия ошибки цикла
      } // конец разбора кликов режима управления
      execClickCount = 0;
    } // конец условия обработки кликов
 
    // Keep-alive
    if ((millis() - pingTimer) > pingTimeout) {
      currentTxPower = servicePower;
      radio.setOutputPower(currentTxPower);
      if (commSession(CMD_EXEC_CONFIG, 1, CMD_EXEC_CONFIG_OK, 500, WORK_COMM_ATTEMPTS)) {
        execBlinkActive = true; execBlinkStartTime = millis(); 
      } else {
        DEBUGln(F("[ERROR] Exec Config Keepalive Failed! -> Exit to STATE_NORMAL"));
        currentState = STATE_NORMAL; updateStatusLed(false); flashStatusLed(2); 
      } // конец условия ошибки связи
      pingTimer = millis(); 
    } // конец проверки интервала пинга
 } // конец функции processExecConfigStandby
 
 // Постоянный контроль качества связи (Heartbeat) в рабочем режиме
 void processPing() {
    if (!buttonPressedFirstTime) return; // Пинг начинается только после первого клика
    
    if (pingFlash) {
      if ((millis() - pingFlashTimer) > PING_FLASH) {
        pingFlash = false; updateStatusLed(currButtonState);
      } // конец условия гашения вспышки
    } else if ((millis() - pingTimer) > pingTimeout) {
      
      // Если динамическая мощность выключена - форсируем максимум
      if (!dynamicPower) {
        currentTxPower = maxPower;
      }
 
      // Упаковка мощности (currentTxPower + 10) и состояния кнопки (бит 7)
      byte safePower = (byte)(constrain(currentTxPower, -9, 22) + 10);
      byte packedData = (currButtonState << 7) | (safePower & 0x7F);
      
      radio.setOutputPower(currentTxPower);
      DEBUG(F("[PING] Tx Power: ")); DEBUG(currentTxPower); DEBUGln(F(" dBm"));
      
      if (commSession(CMD_PING, packedData, CMD_PING_OK, 500, WORK_COMM_ATTEMPTS)) {
        updateStatusLed(!currButtonState); pingFlash = true;
        pingFlashTimer = millis(); pingTimer = millis();
        
        if (dynamicPower) {
            // Распаковка RSSI из ответа
            byte rssiRaw = rcvData & 0x7F;
            int rxRssi = -(int)(rssiRaw + 30);
            
            // Изменение: Разделен лог RSSI на локальный и удаленный для удобства диагностики
            DEBUG(F("[PING] Response RSSI: ")); DEBUGln(radio.getRSSI());
            DEBUG(F("[PING] Loopback RSSI: ")); DEBUGln(rxRssi);
            
            // Вычисление Дельты и Адаптация мощности
            int pathLoss = currentTxPower - rxRssi;
            int idealPower = targetRssi + pathLoss;
            
            if (idealPower > currentTxPower) {
              currentTxPower = idealPower; // Fast UP
            } else if (idealPower < currentTxPower) {
              // Безопасный спуск по алгоритму половины пути
              int safeTarget = idealPower;
              if (safeTarget < minPower) safeTarget = minPower; 
              int nextPower = (currentTxPower + safeTarget) / 2;
              if (currentTxPower - nextPower < 1) nextPower = currentTxPower - 1;
              currentTxPower = nextPower;
            } // конец проверки направления мощности
        } else {
            DEBUGln(F("[PING] Dynamic Power OFF. Using maxPower."));
            currentTxPower = maxPower;
        } // конец проверки флага dynamicPower
        
        currentTxPower = constrain(currentTxPower, minPower, maxPower);
        DEBUG(F("[PING] Adaptive Next Power: ")); DEBUG(currentTxPower); DEBUGln(F(" dBm"));
        
      } else { 
        flashStatusLed(2); 
        currentTxPower = maxPower; // Panic Mode: возврат на максимум при потере связи
        DEBUGln(F("[PING] Link Lost! Reset to maxPower"));
      } // Ошибка связи: двойная вспышка
    } // конец проверки таймера пинга
    
    if ((millis() - lastButtonTime) > bigTimeout) {
      flashStatusLed(3); buttonPressedFirstTime = false;
    } // конец условия таймаута неактивности
 } // конец функции processPing
 
 // ======================= ОСНОВНЫЕ ФУНКЦИИ (SETUP & LOOP) =======================
 
 void setup() {
    // --- СНЯТИЕ ЗАМОРОЗКИ ПИНОВ ПОСЛЕ СНА ---
    gpio_hold_dis((gpio_num_t)PIN_VEXT);
    gpio_hold_dis((gpio_num_t)PIN_ADC_CTRL);
    gpio_deep_sleep_hold_dis();
    // ----------------------------------------
 
    // --- ОТКЛЮЧЕНИЕ RF-МОДЕМА НА СТАРТЕ ДЛЯ ЭКОНОМИИ ЭНЕРГИИ ---
    WiFi.mode(WIFI_OFF);
    // -----------------------------------------------------------
 
 #ifdef DEBUG_ENABLE
    Serial.begin(115200);
    while (!Serial); 
 #endif
 
    // Изменение: Форматирование стартового лога по правилам (10 символов '=', название, модуль, версия, макросы времени)
    DEBUGln(F("========== DavayLoRa TX v1.68 =========="));
    DEBUG(F("[INFO] Compiled: ")); DEBUG(__DATE__); DEBUG(F(" ")); DEBUGln(__TIME__);
    
    DEBUGln(F("[STATE] Initializing GPIO pins..."));
    pinMode(PIN_BUTTON, INPUT_PULLUP);
    pinMode(PIN_USER, INPUT_PULLUP); 
    pinMode(PIN_FB_LED, OUTPUT);
    updateStatusLed(false);
 
    DEBUGln(F("[STATE] Loading NVS config..."));
    loadConfig();
    
    // Синхронизация стартовой мощности с лимитом из конфигурации
    currentTxPower = maxPower;
 
    DEBUGln(F("[STATE] Running wake-up protection..."));
    runWakeUpProtection(PIN_BUTTON);
    delay(2000);
 
    DEBUG(F("Work Channel/Address: ")); DEBUGln(workAddress);
    DEBUG(F("TX BIG Brightness: ")); DEBUGln(pwmledBrightness);
    DEBUG(F("TX FB Brightness: ")); DEBUGln(fbledBrightness);
    DEBUG(F("Dynamic Power: ")); DEBUGln(dynamicPower ? "ON" : "OFF");
    DEBUG(F("Max Power Limit: ")); DEBUGln(maxPower);
    DEBUG(F("Min Power Limit: ")); DEBUGln(minPower);
    DEBUG(F("Service Power: ")); DEBUGln(servicePower);
    
    DEBUGln(F("[STATE] ---> STATE_NORMAL (Boot)"));
 
    DEBUGln(F("[STATE] Powering up peripherals (VEXT/ADC)..."));
    pinMode(PIN_VEXT, OUTPUT); digitalWrite(PIN_VEXT, HIGH);
    pinMode(PIN_ADC_CTRL, OUTPUT); digitalWrite(PIN_ADC_CTRL, HIGH);
    pinMode(PIN_BIG_LED, OUTPUT); analogWrite(PIN_BIG_LED, 0);
    pinMode(PIN_BATTERY_LED, OUTPUT); digitalWrite(PIN_BATTERY_LED, LOW);
 
    DEBUGln(F("[ACTION] Testing LEDs..."));
    updateStatusLed(true); analogWrite(PIN_BIG_LED, pwmledBrightness); digitalWrite(PIN_BATTERY_LED, HIGH); delay(1000);
    updateStatusLed(false); analogWrite(PIN_BIG_LED, 0); digitalWrite(PIN_BATTERY_LED, LOW); delay(1000);
 
    DEBUGln(F("[ACTION] Checking battery status..."));
    if (measurebattery) {
      isBatteryConnected = testBattery(); 
      if (isBatteryConnected) { 
        DEBUGln(F("[ACTION] Battery connected. Showing voltage (2 times)."));
        processBattery(); delay(500); showBatteryVoltage(); delay(2000); showBatteryVoltage(); delay(500);
      } else {
        DEBUGln(F("[ACTION] No battery detected."));
        showNoBattery(); delay(500); 
      } // конец условия обработки подключенной батареи
    } else {
      DEBUGln(F("[ACTION] Battery measurement disabled in config."));
    } // конец условия проверки включения замеров батареи
 
    DEBUGln(F("[STATE] Initializing LoRa radio..."));
    SPI.begin(sckPin, misoPin, mosiPin, csPin);
    workFrequency = 434000000 + ( (workAddress % MAX_ADDRESS) * 200000 );
    int state = radio.begin(workFrequency / 1000000.0);
    if (state != RADIOLIB_ERR_NONE) while (true) { flashStatusLed(6); delay(4000); }
    setLoRaParams();
    
    // Максимальная чувствительность приемника
    radio.setRxBoostedGainMode(true);
    
    radio.setDio1Action(setFlag);
    radio.startReceive();
    
    // --- СНИЖЕНИЕ ЧАСТОТЫ ПРОЦЕССОРА ТОЛЬКО ПОСЛЕ ПОЛНОЙ ИНИЦИАЛИЗАЦИИ ---
    // Спасает стек ipc1 от переполнения на старте!
    setCpuFrequencyMhz(80);
    // ---------------------------------------------------------------------
    
    // Изменение: Финальный лог setup по правилам
    DEBUGln(F("[ACTION] SETUP COMPLETE "));
 } // конец функции setup
 
 void loop() {
    checkReceive(); 
    
    if ((millis() - lastButtonTime) > DEBOUNCE_TIME) processButton();
    processUserButton(); 
    
    // Удержание кнопки 10 секунд для входа в режим подготовки
    if (currentState == STATE_NORMAL && currButtonState) {
      if (millis() - buttonPressStartTime > 10000) {
        DEBUGln(F("[STATE] ---> STATE_PREPARATION"));
        currentState = STATE_PREPARATION; prepModeTimer = millis(); prepClickCount = 0;
        updateBIGLed(false); buttonPressedFirstTime = false; 
      } // конец условия перехода в подготовку
    } // конец условия зажатия кнопки
 
    // Маршрутизация логики в зависимости от текущего состояния
    if (currentState == STATE_NORMAL) processPing();
    else if (currentState == STATE_PREPARATION) processPreparationMode();
    else if (currentState == STATE_CONFIG_STANDBY) processConfigStandby();
    else if (currentState == STATE_EXEC_CONFIG) processExecConfigStandby();
    
    // Обработка Wi-Fi портала, если он запущен
    if (isWifiActive) {
      dnsServer.processNextRequest();
      server.handleClient();
      
      if (exitConfigRequested || (millis() - wifiStartTime > configTimeout)) {
        if (millis() - wifiStartTime > configTimeout) DEBUGln(F("[STATE] WiFi Portal Timeout -> Exit to STATE_NORMAL"));
        else DEBUGln(F("[STATE] ---> STATE_NORMAL (Exited via Web UI)"));
        stopWiFiPortal();
        currentState = STATE_NORMAL; updateStatusLed(false);
      } // конец условия выхода из WiFi
    } // конец условия работы WiFi
    
    EVERY_MS(batteryPeriod) { 
      if (measurebattery && isBatteryConnected) processBattery(); 
    } // конец интервала проверки батареи
 
    // --- FREERTOS YIELD: Передача управления ОС для охлаждения процессора и экономии батареи ---
    delay(1); 
 } // конец функции loop
```

---

## File: .\src\RadioComm.cpp
```cpp
/**
 * @file RadioComm.cpp
 * @version 1.53
 * @brief Реализация радиосвязи SX1262 (TX)
 */
 #include "RadioComm.h"
 #include "Config.h"
 
 // Локальные макросы отладки
 #define DEBUG_ENABLE // Логирование выключено
 #ifdef DEBUG_ENABLE
 #define DEBUG(x) Serial.print(x)
 #define DEBUGln(x) Serial.println(x)
 #else
 #define DEBUG(x)
 #define DEBUGln(x)
 #endif
 
 extern const int sckPin = 9;
 extern const int misoPin = 11;
 extern const int mosiPin = 10;
 extern const int csPin = 8;
 extern const int resetPin = 12;
 extern const int irqPin = 14;
 extern const int busyPin = 13;
 
 SX1262 radio = new Module(csPin, irqPin, resetPin, busyPin);
 
 byte sndCmd = CMD_PING;
 byte sndData;
 bool wasReceived = false;
 byte cmdExpected = CMD_PING_OK;
 byte rcvAddress = 0;
 byte rcvCmd = 0;
 byte rcvData;
 unsigned long workFrequency = WORK_FREQUENCY;
 
 long lastSendTime = 0;
 int lastRSSI;
 float lastSNR;
 unsigned long lastTurnaround = DEFAULT_TURNAROUND;
 long lastFrequencyError;
 
 volatile bool receivedFlag = false; 
 
//  // Список рабочих частот. Выбор частоты зависит от адреса устройства.
//  unsigned long workingFrequency[MAX_ADDRESS] = {
//     434000000, 434120000, 434240000, 433820000, 433700000, 433940000, 434030000,
//     434150000, 434270000, 433850000, 433730000, 433970000, 434060000, 434180000,
//     433880000, 433760000, 434090000, 434210000, 433910000, 433790000,
//  };
// теперь будет вычисляться по формуле: 434000000 + (адрес * 20000)

 #if defined(ESP8266) || defined(ESP32)
    ICACHE_RAM_ATTR
 #endif
 void setFlag(void) {
    receivedFlag = true;
 } // конец функции прерывания setFlag
 
 void transmitPacket(byte* payload, size_t size) {
    DEBUG(F("[RADIO] >>> TX Packet [Size: ")); DEBUG(size); DEBUG(F("]: "));
    for (size_t i = 0; i < size; i++) { DEBUG(payload[i]); DEBUG(F(" ")); }
    DEBUGln();
 
    int state = radio.transmit(payload, size);
    if (state != RADIOLIB_ERR_NONE) {
      DEBUG(F("[RADIO] >>> Transmit failed, code: ")); DEBUGln(state);
    } // конец проверки ошибки передачи
    
    lastSendTime = millis();
    receivedFlag = false; 
    radio.startReceive(); // Сразу переходим обратно в режим приема
 } // конец функции transmitPacket
 
 // Стандартная отправка 3-байтового пакета (Адрес, Команда, Данные)
 void sendMessage(byte msgCmd, byte sndData) {
    byte payload[3] = {workAddress, msgCmd, sndData};
    transmitPacket(payload, 3);
 } // конец функции sendMessage
 
 void checkReceive() {
    if (receivedFlag) {
      receivedFlag = false;
      byte payload[256];
      int state = radio.readData(payload, sizeof(payload));
      
      if (state == RADIOLIB_ERR_NONE) {
        int packetSize = radio.getPacketLength();
        onReceive(payload, packetSize);
      } // конец проверки успешного приема
      radio.startReceive();
    } // конец проверки флага прерывания
 } // конец функции checkReceive
 
 // Сессия связи: отправка команды и ожидание подтверждения (с повторными попытками)
 bool commSession(byte msgCmd, byte sndData, byte expectedReply, unsigned long waitMilliseconds, int doTimes) {
    DEBUG(F("[RADIO] Starting CommSession for CMD: ")); DEBUGln(msgCmd);
    wasReceived = false;
    cmdExpected = expectedReply; 
    pingTimer = millis();
    unsigned long lastSend = millis() - waitMilliseconds; 
    
    do {
      checkReceive();
      if (millis() - lastSend >= waitMilliseconds) {
        sendMessage(msgCmd, sndData);
        lastSend = millis();
        doTimes--;
      } // конец интервальной отправки
    } while ((doTimes > 0) && (!wasReceived)); // конец цикла попыток
    
    pingTimer = millis();
    if (wasReceived) { DEBUGln(F("[RADIO] CommSession SUCCESS")); }
    else { DEBUGln(F("[RADIO] CommSession FAILED (Timeout/No Reply)")); }
    return wasReceived; 
 } // конец функции commSession
 
 // Передача структуры настроек на приемник
 bool syncConfigToRX() {
    DEBUGln(F("[RADIO] --- Syncing Config Struct to RX ---"));
    DEBUG(F("workAddress: ")); DEBUGln(rxSettings.workAddress);
    DEBUG(F("rxPwmledBrightness: ")); DEBUGln(rxSettings.rxPwmledBrightness);
    DEBUG(F("rxBuzzerVolume: ")); DEBUGln(rxSettings.rxBuzzerVolume);
 
    wasReceived = false;
    cmdExpected = CMD_SYNC_CONFIG_OK;
    
    byte txBuffer[sizeof(ConfigPacket) + 2];
    txBuffer[0] = workAddress; 
    txBuffer[1] = CMD_SYNC_CONFIG;
    memcpy(&txBuffer[2], &rxSettings, sizeof(ConfigPacket));
 
    for (int i=0; i < 3; i++) {
      transmitPacket(txBuffer, sizeof(txBuffer));
 
      unsigned long startWait = millis();
      while (millis() - startWait < 500) { 
        checkReceive();
        if (wasReceived) {
          DEBUGln(F("[RADIO] --- RX Confirmed Sync! ---"));
          return true;
        } // конец условия приема подтверждения
      } // конец цикла ожидания ответа
    } // конец цикла попыток синхронизации
    DEBUGln(F("[RADIO] --- RX Sync Timeout! ---"));
    return false;
 } // конец функции syncConfigToRX
 
 // Базовые параметры LoRa: Максимальная мощность и дальнобойные настройки
 void setLoRaParams() {
    DEBUGln("[RADIO] setLoRaParams()");
    radio.setOutputPower(20);
    radio.setBandwidth(125.0);
    radio.setSpreadingFactor(8);
    radio.setCodingRate(5);
    radio.setPreambleLength(8);     
    radio.setSyncWord(RADIOLIB_SX126X_SYNC_WORD_PRIVATE); 
 } // конец функции setLoRaParams
 
 void onReceive(byte* payload, int packetSize) {
    DEBUG(F("[RADIO] <<< RX Packet [Size: ")); DEBUG(packetSize); DEBUG(F("]: "));
    for (int i = 0; i < packetSize; i++) { DEBUG(payload[i]); DEBUG(F(" ")); }
    DEBUGln();
 
    if (packetSize != 3) {
      DEBUGln(F("\t[!] Invalid packet size! Expected 3 bytes."));
      return;
    } // конец проверки длины пакета
 
    rcvAddress = payload[0];
    if ((rcvAddress != workAddress) && rcvAddress != 255) { 
      DEBUGln(F("\t[!] Ignored: Wrong address"));
      return;
    } // конец проверки адреса
 
    rcvCmd = payload[1];
    if (rcvCmd != cmdExpected) {
      DEBUGln("\t[!] Invalid Reply: " + String(rcvCmd) + F(", Expected: ") + String(cmdExpected));
      return;
    } // конец проверки команды
    rcvData = payload[2];
 
    lastTurnaround = millis() - lastSendTime;
    lastRSSI = radio.getRSSI();
    lastSNR = radio.getSNR();
    
    DEBUGln(("\tTurnaround: ") + String(lastTurnaround));
    wasReceived = true; 
 } // конец функции onReceive
```

---

## File: .\src\RadioComm.h
```cpp
/**
 * @file RadioComm.h
 * @version 1.53
 * @brief Модуль радиосвязи SX1262 и протокол (TX)
 * Описание: Отвечает за прием и передачу пакетов, содержит коды команд протокола.
 */
 #ifndef RADIOCOMM_H
 #define RADIOCOMM_H
 
 #include <Arduino.h>
 #include <RadioLib.h>
 #include <SPI.h>
 
 // --- Макросы команд (Протокол связи v1.53) ---
 #define CMD_SIGNAL         208  // Передача состояния главной кнопки
 #define CMD_SIGNAL_OK      209  // Подтверждение приема сигнала
 #define CMD_PING           212  // Контроль качества связи (Keep-alive)
 #define CMD_PING_OK        213  // Подтверждение пинга
 #define CMD_SLEEP          214  // Централизованная команда на засыпание
 #define CMD_SLEEP_OK       215  // Подтверждение сна
 #define CMD_CONFIG         216  // Синхронный переход в режим настройки (Web)
 #define CMD_CONFIG_OK      217  // Подтверждение режима настройки
 #define CMD_NORMAL_MODE    218  // Принудительный возврат в рабочий режим
 #define CMD_NORMAL_MODE_OK 219  // Подтверждение возврата
 #define CMD_SYNC_CONFIG    220  // Отправка структуры с настройками на RX
 #define CMD_SYNC_CONFIG_OK 221  // Успешная синхронизация настроек
 #define CMD_REBOOT         222  // Приказ на немедленную перезагрузку приемника
 #define CMD_EXEC_CONFIG    223  // Переход в режим изменения сигналов на лету
 #define CMD_EXEC_CONFIG_OK 224  // Подтверждение режима изменения сигналов
 #define CMD_CYCLE_EXEC     225  // Команда переключения исполнительных устройств (свет/вибро)
 #define CMD_CYCLE_EXEC_OK  226  // Подтверждение переключения
 
 #define WORK_FREQUENCY 434E6
 #define MAX_ADDRESS 81
 #define DEFAULT_TURNAROUND 300     
 #define WORK_COMM_ATTEMPTS 3       
 
 // --- Пины и объекты ---
 extern const int sckPin;
 extern const int misoPin;
 extern const int mosiPin;
 extern const int csPin;
 extern const int resetPin;
 extern const int irqPin;
 extern const int busyPin;
 
 extern SX1262 radio;
 
 // --- Переменные радиообмена ---
 extern byte sndCmd;
 extern byte sndData;
 extern bool wasReceived;
 extern byte cmdExpected;
 extern byte rcvAddress;
 extern byte rcvCmd;
 extern byte rcvData;
 extern unsigned long workFrequency;
 
 extern long lastSendTime;
 extern int lastRSSI;
 extern float lastSNR;
 extern unsigned long lastTurnaround;
 extern long lastFrequencyError;
 
 extern volatile bool receivedFlag; 
 
 //extern unsigned long workingFrequency[MAX_ADDRESS];
 
 // Внешние переменные из main.cpp
 extern unsigned long pingTimer;
 
 // --- Прототипы ---
 void setFlag(void);
 void transmitPacket(byte* payload, size_t size);
 void sendMessage(byte msgCmd, byte sndData);
 void checkReceive();
 bool commSession(byte msgCmd, byte sndData, byte expectedReply, unsigned long waitMilliseconds, int doTimes);
 bool syncConfigToRX();
 void setLoRaParams();
 void onReceive(byte* payload, int packetSize);
 
 #endif
```

---

## File: .\src\webpage.h
```cpp
/**
 * @file webpage.h
 * @version 1.71 (Добавлен справочный вывод рабочей частоты %FREQ_MHZ%)
 * @brief HTML-интерфейс для Captive Portal (TX)
 */

 #ifndef WEBPAGE_H
 #define WEBPAGE_H
 
 #include <Arduino.h>
 
 const char index_html[] PROGMEM = R"rawliteral(
 <!DOCTYPE HTML>
 <html lang="ru">
 <head>
    <meta charset="UTF-8">
    <meta name="viewport" content="width=device-width, initial-scale=1">
    <title>DavayLoRa Config</title>
    <style>
      body { font-family: 'Segoe UI', Tahoma, Geneva, Verdana, sans-serif; background-color: #121212; color: #ffffff; padding: 15px; max-width: 600px; margin: 0 auto; }
      h2 { text-align: center; color: #4CAF50; margin-bottom: 10px; font-size: 24px;}
      .timer { text-align: center; color: #ff9800; font-size: 18px; margin-bottom: 20px; font-weight: bold; }
      fieldset { border: 1px solid #4CAF50; border-radius: 8px; margin-bottom: 25px; padding: 20px; background: #1e1e1e; }
      legend { color: #4CAF50; font-weight: bold; font-size: 18px; padding: 0 10px; }
      label { display: block; margin-top: 15px; margin-bottom: 5px; color: #cccccc; font-size: 14px; }
      input[type="number"] { width: 100%; padding: 12px; border-radius: 6px; border: 1px solid #444; background: #2a2a2a; color: #fff; box-sizing: border-box; font-size: 16px; transition: border 0.3s; }
      input[type="number"]:focus { border-color: #4CAF50; outline: none; }
      .checkbox-container { display: flex; align-items: center; margin-top: 15px; background: #2a2a2a; padding: 12px; border-radius: 6px; }
      input[type="checkbox"] { transform: scale(1.5); margin: 0 10px 0 5px; accent-color: #4CAF50; }
      .checkbox-container span { font-size: 15px; color: #fff; }
      .buttons-container { display: flex; flex-direction: column; gap: 15px; margin-bottom: 30px; margin-top: 10px; }
      input[type="submit"] { background-color: #4CAF50; color: white; padding: 16px; border: none; border-radius: 6px; cursor: pointer; width: 100%; font-size: 18px; font-weight: bold; transition: background 0.3s; box-shadow: 0 4px 6px rgba(0,0,0,0.3); box-sizing: border-box; }
      input[type="submit"]:hover { background-color: #45a049; }
      .cancel-btn { background-color: #f44336; color: white; text-decoration: none; padding: 16px; display: flex; align-items: center; justify-content: center; border-radius: 6px; width: 100%; font-size: 18px; font-weight: bold; transition: background 0.3s; box-shadow: 0 4px 6px rgba(0,0,0,0.3); box-sizing: border-box; }
      .cancel-btn:hover { background-color: #d32f2f; }
    </style>
    <script>
      let timeLeft = %TIME_LEFT%;
      function updateTimer() {
        if (timeLeft <= 0) {
          document.getElementById('timeDisplay').innerText = "00:00";
          alert("⏳ Время конфигурации истекло!");
          window.location.reload();
          return;
        }
        let m = Math.floor(timeLeft / 60).toString().padStart(2, '0');
        let s = (timeLeft % 60).toString().padStart(2, '0');
        document.getElementById('timeDisplay').innerText = m + ":" + s;
        timeLeft--;
        setTimeout(updateTimer, 1000);
      }
      window.onload = updateTimer;
    </script>
 </head>
 <body>
    <h2>⚙️ Настройка DavayLoRa</h2>
    <div class="timer">⏳ До автовыхода: <span id="timeDisplay">--:--</span></div>
    <div style="text-align: center; color: #4CAF50; font-size: 16px; margin-bottom: 20px; font-weight: bold;">📡 Рабочая частота: %FREQ_MHZ% МГц</div>

    <form action="/save" method="POST">
      <fieldset>
        <legend>🌍 Общие настройки</legend>
        <label title="434-450 МГц, шаг 0.2">Рабочий канал (0-80):</label>
        <input type="number" name="workAddress" value="%ADDR%" min="0" max="80" required>

        <label title="По умолчанию: 20 dBm">Максимальная мощность (0-22 дБм):</label>
        <input type="number" name="maxPower" value="%MAX_PWR%" min="0" max="22" required>
        
        <div class="checkbox-container">
          <input type="checkbox" name="measurebattery" value="1" %BAT_CHK% title="По умолчанию: Включено">
          <span>Включить проверку батареи</span>
        </div>
        <label title="По умолчанию: 300000 мс (5 минут)">Период проверки батареи (мс):</label>
        <input type="number" name="batteryPeriod" value="%BAT_PER%" min="10000" step="1000" required>
        <label title="По умолчанию: 2000 мс">Время удержания при вкл. (мс):</label>
        <input type="number" name="wakeUpHoldTime" value="%WK_HOLD%" min="100" step="100" required>
        <label title="По умолчанию: 2000 мс">Окно отпускания при вкл. (мс):</label>
        <input type="number" name="wakeUpReleaseWindow" value="%WK_REL%" min="100" step="100" required>
        <label title="По умолчанию: 10000 мс (10 сек)">Таймаут заклинивания вкл. (мс):</label>
        <input type="number" name="stuckSleepTime" value="%STUCK_SL%" min="1000" step="1000" required>
        <label title="По умолчанию: 600000 мс (10 минут)">Таймаут настроек (мс):</label>
        <input type="number" name="configTimeout" value="%CONF_TO%" min="60000" step="10000" required>
        <label title="По умолчанию: 2000 мс">Индикация выключения (мс):</label>
        <input type="number" name="sleepLedDuration" value="%SLP_LED%" min="100" step="100" required>
      </fieldset>
 
      <fieldset>
        <legend>🔘 Пульт (TX)</legend>
        <div class="checkbox-container">
          <input type="checkbox" name="dynamicPower" value="1" %DYN_PWR% title="По умолчанию: Включено">
          <span>Переменная мощность (Адаптация)</span>
        </div>
        <label title="По умолчанию: -9 дБм">Минимальная мощность (-9...0 дБм):</label>
        <input type="number" name="minPower" value="%MIN_PWR%" min="-9" max="0" required>
        <label title="По умолчанию: 18 дБм">Мощность настройки (0-22 дБм):</label>
        <input type="number" name="servicePower" value="%SRV_PWR%" min="0" max="22" required>
        
        <label title="По умолчанию: 35">Яркость LED (0-255):</label>
        <input type="number" name="pwmledBrightness" value="%TX_BIG_LED%" min="0" max="255" required>
        <label title="По умолчанию: 255">Яркость кнопки (0-255):</label>
        <input type="number" name="fbledBrightness" value="%TX_FB_LED%" min="0" max="255" required>
        <label title="По умолчанию: 3000 мс">Таймаут Пинга (мс):</label>
        <input type="number" name="pingTimeout" value="%TX_PING%" min="1000" step="100" required>
        <label title="По умолчанию: 3600000 мс (1 час)">Таймаут отключения Пинга (мс):</label>
        <input type="number" name="bigTimeout" value="%TX_BIG_TO%" min="10000" step="1000" required>
        <label title="По умолчанию: 30000 мс (30 сек)">Таймаут настроек сигнала (мс):</label>
        <input type="number" name="execTimeout" value="%TX_EXEC_TO%" min="10000" step="1000" required>
      </fieldset>
 
      <fieldset>
        <legend>💡🔔 Приёмник (RX)</legend>
        <div class="checkbox-container">
          <input type="checkbox" name="rxEnableBigLed" value="1" %RX_BIG_EN% title="По умолчанию: Включено">
          <span>Включить светодиод</span>
        </div>
        <label title="По умолчанию: 35">Яркость светодиода (0-255):</label>
        <input type="number" name="rxPwmledBrightness" value="%RX_BIG_LED%" min="0" max="255" required>
        <div class="checkbox-container">
          <input type="checkbox" name="rxEnableBuzzer" value="1" %RX_BUZ_EN% title="По умолчанию: Выключено">
          <span>Включить вибратор</span>
        </div>
        <label title="По умолчанию: 255">Громкость вибратора (0-255):</label>
        <input type="number" name="rxBuzzerVolume" value="%RX_BUZ_VOL%" min="0" max="255" required>
        <label title="По умолчанию: 2000 мс">Отсечка постоянного нажатия (мс):</label>
        <input type="number" name="rxCutoffTime" value="%RX_CUTOFF%" min="100" step="100" required>
        <label title="По умолчанию: 9000 мс (9 сек)">Таймаут потери Пинга RX (мс):</label>
        <input type="number" name="pingTimeoutRX" value="%RX_PING%" min="1000" step="100" required>
      </fieldset>
 
      <div class="buttons-container">
        <input type="submit" value="💾 Сохранить и Перезагрузить">
        <a href="/cancel" class="cancel-btn">❌ Отмена</a>
      </div>
    </form>
 </body>
 </html>
 )rawliteral";
 
 #endif
```

---
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

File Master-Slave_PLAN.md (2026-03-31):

План модернизации системы связи «DavayLoRa» (Master-Slave Архитектура)

*Этап 1. Интеграция энергонезависимой памяти (NVS) — [ВЫПОЛНЕНО]*

*Этап 2. Стейт-машина пульта (TX), глубокий сон и управление RX*

Шаг 2.1: Режим подготовки (Preparation Mode) на TX.

Реализация отслеживания непрерывного удержания кнопки в течение 10 секунд.

Переход в новый системный режим с индикацией быстрого мигания (3 Гц).

Таймер отложенного выхода: возврат к нормальной работе при отсутствии действий в течение 10 секунд.

Шаг 2.2: Централизованное выключение (Сон).

Добавление парсера 2-х коротких нажатий в режиме подготовки на TX.

При срабатывании TX отправляет по радиоканалу новую команду CMD_SLEEP на RX.

RX, получив команду, мигает статусным диодом и аппаратно уходит в глубокий сон (esp_deep_sleep_start).

TX, дождавшись подтверждения (ACK) от RX, зажигает диод на 2 секунды и также уходит в глубокий сон.

Шаг 2.3: Защита пробуждения пульта.

Пробуждение процессора TX по аппаратному прерыванию от кнопки (ext0 wakeup).

Программный барьер: если кнопка была отпущена быстрее, чем через 2 секунды после пробуждения — мгновенный возврат в сон (защита от случайных нажатий в сумке).

Шаг 2.4: Триггер конфигурации.

Парсинг 3-х коротких нажатий в режиме подготовки.

Индикация процесса (3 вспышки -> пауза 1 сек).

Принудительный пинг RX. При успехе — переход в логику WiFi, при неудаче — индикация ошибки и возврат в режим подготовки.

*Этап 3. Локальное управление питанием Приёмника (RX)*

Шаг 3.1: Интеграция магнитного датчика.

Подключение цифрового датчика Холла/геркона к RTC-пину RX.

Логика аппаратного пробуждения RX от магнита (так как по радиоканалу разбудить спящий ESP32 невозможно).

(Опционально) Резервное локальное усыпление RX магнитом.

*Этап 4. Master-Slave Конфигурация (WiFi + LoRa OTA)*

Шаг 4.1: WiFi Captive Portal на TX. Поднятие точки доступа и HTML-интерфейса.

Шаг 4.2: Формирование OTA-пакета. Упаковка новых настроек в радиопакет CMD_NEW_CONFIG.

Шаг 4.3: Применение на RX. Распаковка, сохранение в NVS и отправка ACK.

Шаг 4.4: Синхронная перезагрузка. Перезапуск обеих плат для применения новых частот/адресов.
**DONE ALL**

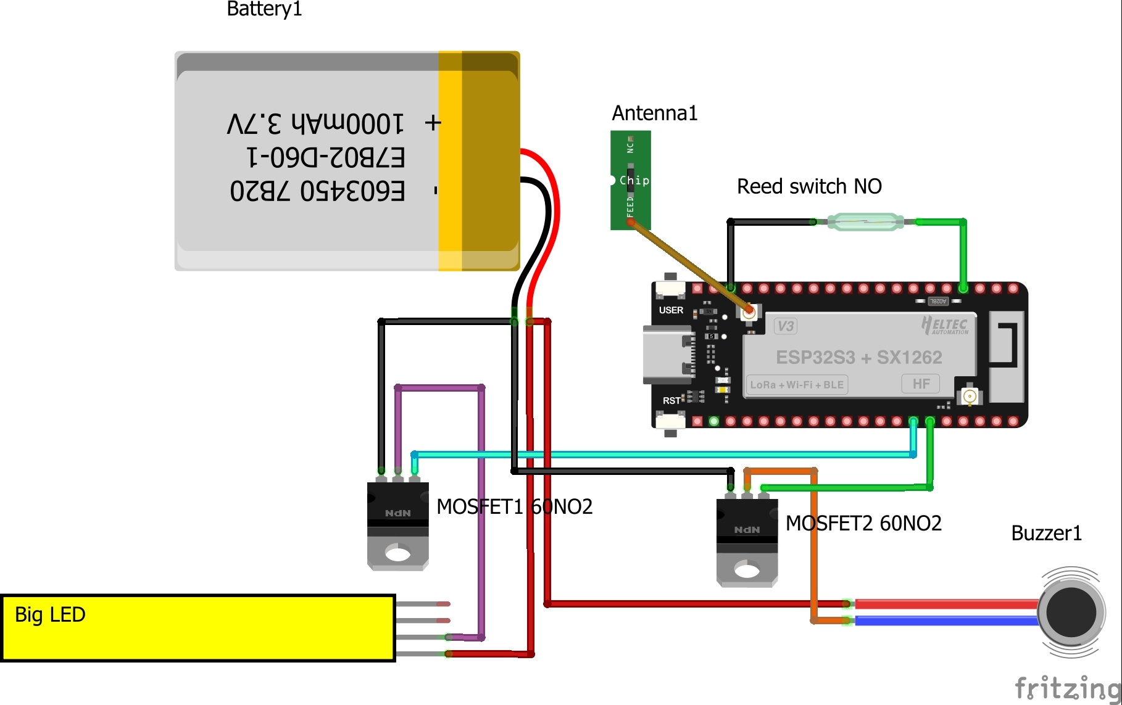
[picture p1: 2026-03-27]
DavayLoRa_HT_RX_bb.jpg

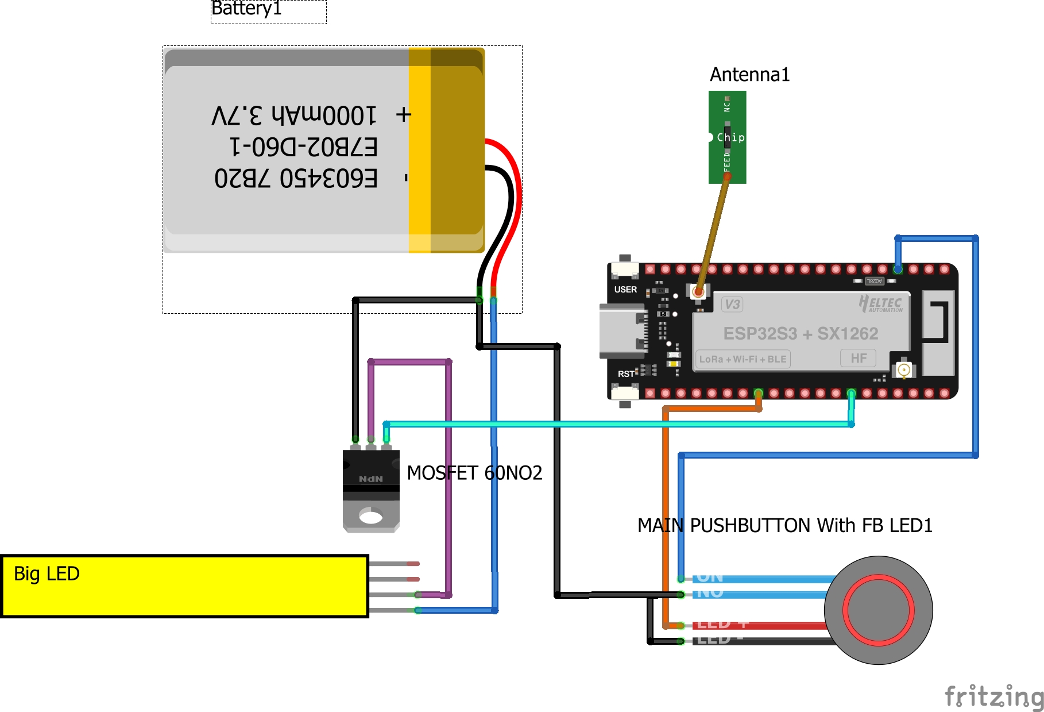
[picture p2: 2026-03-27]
DavayLoRa_HT_TX_bb.jpg

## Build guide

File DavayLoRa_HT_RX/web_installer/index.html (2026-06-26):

# Прошивка DavayLoRa_RX

Подключите ваше устройство Heltec V3 (ESP32-S3) к компьютеру по USB.

Нажмите кнопку ниже и выберите COM-порт устройства во всплывающем окне.

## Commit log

2022-01-07 New Repository for DavayLoRa
    [DavayLoRa_BSF_RX1.fzz, DavayLoRa_BSF_TX1.fzz]
2022-01-10 «причёсан» предыдущий код. Добавлены схемы соединения. Новый репозиторий github.
    [DavayLoRa_BSF_RX1.fzz]
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2022-01-17 17.01.2022 - после проверки работы с севшими батарейками немного изменены напряжения отсечки 17.01.2022 - Добавлено 1-секундное «приветствие» (а то севшие батарейки не мигали совсем)
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2022-01-18 - 18.01.2022 - Исправлена бага со включением баззера и биппера на старте.
2022-01-18 - 18.01.2022 - В приветствие на старте добавлено включение всех исполнительных элементов. - 18.01.2022 - Добавлены инструкции для успешной работы с модулями с неисправным измерителем напряжения.
2022-01-29 29-01-2022 Зафиксированы изменения Никиты: - Диапазоны батареек - Неработающий встроенный измеритель напряжения - Рабочий адрес Исправлен баг с непроверкой рабочего адреса на приёмнике
2022-02-01 - 01.02.2022 - Попытка ослабить влияние приборов разных пар, работающих на одной частоте. - использованы Sync Word - добавлена подстройка частоты на приёмнике - добавлена задержка при получении несво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
2022-02-01 - 01.02.2022 - Убран ответный сигнал на «потухание» - уменьшены задержки - Все настройки вынесены в 1 место - сделан ШИМ для Баззера/Биппера
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2022-02-21 - 21.02.2022 - Приёмник: включается статусный ЛЕД вместе с сигналом (на случай выключения всех ДИПов) Вроде бы исправлена бага с «тусклым» статусным ледом для передатчика - НЕ исправлена бага с показ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
2022-02-21 - 22.02.2022 - Выяснена и ПОДправлена бага с показом отсутствия связи при первом нажатии при выключенном приёмнике. Исправить полностью нельзя, поскольку ещё неизвестно реальное время задержки сигнал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
2023-02-27 Изменения при изготовлении первой партии в СПБ
    - - - Изменена схема подключений выключателей. Теперь выключатель вставлен между + батарейного разъёма и контактом BAT. При этом
    перерезается дорожка на плате, соединяющая эти места!
    - - Платы BSFrance сортируются и "хорошие" используются в приёмниках, а "плохие" снабжаются резисторами и используются в передатчиках
    - - В передатчике индикация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
2023-03-01 Changes after small party of 11 devices production
    - In RX - add setting to work without battery measuring
    - Required sorting of BSFrance.
2023-03-05 Поправлены файлы Fritzing
    Переставлен выключатель и убрана монтажная плата
    Поправлены картинки
    [DavayLoRa_BSF_RX1.fzz, DavayLoRa_BSF_TX1.fzz]
2023-03-15 Doc. changes mainly
    - Добавлена программа измерения работы делителя TestBSF
    - Исправлены сигналы - Пинг, батарейные
    - Исправлена документация Whitepaper, Fritzen, Readme, Description - на приёмнике
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2023-03-23 Automatic Battery detection
    Теперь наличие внутреннего делителя для измерения батарейки должно определяться автоматически.
    Если не работает, то проверяется работа делителя на внешних запаянных резисторов на А1.
    Если нет, то должно работать без измерения батарейки
2026-03-12 Remastering of the project code for Cursor and PlatformIO and for ESP32 processor. Этап 1: Подготовка базового кода для Cursor (PlatformIO) - DONE Compile success
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2026-03-16 12. Скомпилировать, прошить и протестировать работу проекта на новых модулях Heltec. - Библиотеки: Удалены LoRa.h и AVR-специфичная GyverPower.h. Добавлены RadioLib.h и esp_sleep.h. - Пины Heltec V3: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
2026-03-25 Исправлено синк-слово в RX и TX radio.setSyncWord(RADIOLIB_SX126X_SYNC_WORD_PRIVATE);
    [main.cpp]
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2026-03-25 Реализация отслеживания непрерывного удержания кнопки в течение 10 секунд. (Не оттестировано!) Новые картинки со схемами и Фритцинг файлы Новый Master-Slave план
    [DavayLoRa_BSF_RX1.fzz, DavayLoRa_BSF_TX1.fzz, DavayLoRa_HT_RX.fzz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]
2026-03-27 Созданы Фритцен файлы для RX и TX
    [DavayLoRa_HT_RX.fzz, DavayLoRa_HT_TX.fzz]
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2026-03-27 Что сделано: Макрос BATTERY_PERIOD удален и заменен на переменную batteryPeriod (по умолчанию 300000 мс). Добавлена переменная sleepLedDuration (по умолчанию 2000 мс). Обе переменные прописаны в функ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
2026-03-27 Имплементация засыпания и пробуждения приборов. Всё кроме ЛоРы засыпает. Лора - следующим шагом. Исправлен Фритцин - кнопка TX теперь подключена к GPIO 7, чтообы срабатывало просыпание.
    [DavayLoRa_HT_TX.fzz]
2026-03-27 Исправление: Остановка радиомодуля SX1262 перед глубоким сном сброс флага receivedFlag = false; в функции отправки обоих приборов (чтобы не читалось эхо)
    [main.cpp]
2026-03-28 Убраны Аппаратные утечки тока (Шина SPI) в режиме сна Изменение: увеличен pingTimeoutRX («Моргание» сирены при потере пакета) Изменение: Добавлена переменная pingTimeoutRX в NVS для будущего портала
2026-03-28 1.15 (Изменение: Защита от "горячего" процессора при заклинивании магнита или кнопки при пробуждении)
2026-03-28 1.16 (Исправление: Убрана системная ошибка Incorrect wakeup source)
    [main.cpp]
2026-03-28 1.17 (Изменение: Добавлена стейт-машина и синхронная индикация CONFIG_STANDBY) Новые команды протокола: CMD_CONFIG (216), CMD_CONFIG_OK (217), CMD_NORMAL_MODE (218) и CMD_NORMAL_MODE_OK (219). Стейт-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
2026-03-28 1.18 (Изменение: Добавлен выход из CONFIG_STANDBY при потере связи TX с RX)
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2026-03-28 1.20 (Изменение: Добавлен запуск WiFi Captive Portal по 1 клику) По короткому клику в режиме STATE_CONFIG_STANDBY пульт (TX) поднимет точку доступа с именем DavayLoRa_TX. Включится DNS-сервер (Captiv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
2026-03-28 1.24 (Изменение: Вывод версии файла в лог, Для вэб страницы: таймер и обработка кнопки Отмена)
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2026-03-29 1.30 (Изменение: Расширенное структурное логирование стейт-машины и действий) Жёстко указаны Com9 для TX и Com10 для RX
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2026-03-29 1.32 Переменная sleepLedDuration соотв. «Индикация выключения (мс)» добавлена в общие параметры и передана на RX.
2026-03-29 1.33 (Исправлен выход из режима подготовки при одиночном клике)
    [main.cpp]
2026-03-29 Версии файлов: Повышены до v1.34 (TX: Режим настройки исполнительных элементов) и v1.34 (RX: Режим настройки исполнительных элементов) соответственно. Протокол: В оба файла добавлены новые команды CM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
2026-03-30 1.42 (TX: Финализация execTimeout - выход из режима настройки актуаторов, строгий аудит)
2026-03-30 1.43 (TX: Восстановление 2х-кратной индикации батареи при старте и полные логи setup) 1.43 (RX: Полное логирование setup и перенос Serial.begin)
2026-03-30 1.44 (TX: Фикс бага аппаратного ШИМ ESP32 при быстром loop) (добавлен флаг)
2026-03-30 1.45 (TX: Оптимизация таймера отправки в commSession) 1.45 (RX: Оптимизация шины APB через кэширование состояния LED чтобы не вызывать DigitalWrite в Лупе)
2026-03-30 1.46 (TX: Оптимизация логов, устранение пустых строк и фиксация всех state) 1.46 (RX: Оптимизация логов, устранение пустых строк)
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2026-03-30 1.49 (TX: Выделение WebPortal, исправление бага с баззером и текста Success)
    [Config.cpp, WebPortal.cpp, main.cpp]
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2026-03-31 1.59 (Добавлено логирование всех состояний кнопки USER), Исправлен баг с записью длины таймера выключения Пока всё.
    [Config.cpp, WebPortal.cpp, main.cpp]
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
